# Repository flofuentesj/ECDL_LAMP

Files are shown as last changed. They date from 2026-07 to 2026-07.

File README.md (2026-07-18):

# Optically-feedback-stabilized-ECDL-
A cost-effective diode laser system for high-resolution atomic spectroscopy, developed at Universidad de Concepción's LAMP laboratory using commercial components. It features an external cavity with a piezoelectric transducer for precise wavelength tuning and stabilization that achieves sub-MHz line width essential for rubidium transitions.
Setup: 
Setup

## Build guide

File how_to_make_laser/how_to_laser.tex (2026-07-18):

\documentclass[12pt]{article}
\usepackage[utf8]{inputenc}
\usepackage{geometry}
\usepackage[T1]{fontenc}
\usepackage{amsfonts}
\usepackage{afterpage}
\usepackage{graphicx}
\usepackage{float}
\usepackage{url}
\usepackage{hyperref}
\usepackage{bookmark}
\usepackage[sorting=none]{biblatex}
\usepackage{multirow}
\usepackage[table,xcdraw]{xcolor}
\usepackage{pgf}
\usepackage{xurl}
\usepackage{tabularray}
\usepackage{tabulary}
\usepackage{fancyhdr}
\usepackage[maxfloats=30,morefloats=12]{morefloats}
\usepackage{multicol}
\usepackage[dvipsnames]{xcolor}
\usepackage{awesomebox}
\usepackage{subcaption}
\usepackage{awesomebox}
\usepackage{pgfornament}
\usepackage[export]{adjustbox}
\usepackage{biblatex} %Imports biblatex package
\usepackage{tikzlings}

\addbibresource{howto.bib} %Import the bibliography file
\fontfamily{put}\selectfont
\setlength{\columnsep}{40pt}
\setlength{\voffset}{0.5cm}
\setlength{\headsep}{40pt}
\setlength{\headheight}{34.06914pt} % Fix for fancyhdr error
\addtolength{\topmargin}{-22.06914pt} % Adjusted top margin as suggested by fancyhdr
\geometry{legalpaper, portrait, margin=2.3cm}

% Header and footer
\pagestyle{fancy}
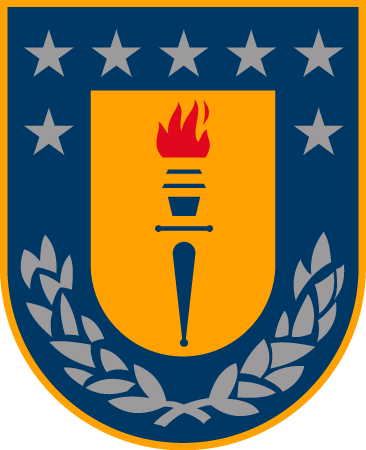
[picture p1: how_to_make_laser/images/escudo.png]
\fancyhead[C]{}
\fancyhead[L]{\textbf{Tópicos II}\\ Universidad de Concepción}
\fancyhead[R]{\textbf{Florencia Fuentes}\\flofuentes2021@udec.cl}
\fancyfoot{}
% for adjust width environment
\usepackage[strict]{changepage}

% for formal definitions
\usepackage{framed}

%\definecolor{formalshade}{rgb}{0.95,0.95,1}
\definecolor{formalshade}{rgb}{.97, .88, .94}

\newenvironment{formal}{
  \def\FrameCommand{
    \hspace{1pt}
    {\color{White}\vrule width 2pt}
    {\color{Lavender}\vrule width 4pt}
    \colorbox{formalshade!40!white}
  }
  \MakeFramed{\advance\hsize-\width\FrameRestore}%
  \noindent\hspace{-4.55pt}% disable indenting first paragraph
  \begin{adjustwidth}{}{7pt}%
  \vspace{2pt}\vspace{2pt}
}
{\vspace{2pt}\end{adjustwidth}\endMakeFramed}

\renewcommand{\headrulewidth}{0.1pt}

\usepackage{tikz}

\usepackage{tcolorbox}
\tcbuselibrary{minted}
\newtcblisting{mybox}{colback=white,minted language=latex,listing side text,righthand width=.5\textwidth}
\usetikzlibrary{ducks}
\usepackage{tikzducks}

\definecolor{titlepagecolor}{cmyk}{0,.49,.15,.11}

\newcommand\titlepagedecoration{%
\begin{tikzpicture}[remember picture,overlay,shorten >= -10pt]

\coordinate (aux1) at ([yshift=-15pt]current page.north east);
\coordinate (aux2) at ([yshift=-410pt]current page.north east);
\coordinate (aux3) at ([xshift=-4.5cm]current page.north east);
\coordinate (aux4) at ([yshift=-150pt]current page.north east);

\begin{scope}[titlepagecolor!70,line width=12pt,rounded corners=12pt]
\draw
  (aux1) -- coordinate (a)
  ++(225:5) --
  ++(-45:5.1) coordinate (b);
\draw[shorten <= -10pt]
  (aux3) --
  (a) --
  (aux1);
\draw[opacity=0.6,titlepagecolor,shorten <= -10pt]
  (b) --
  ++(225:2.2) --
  ++(-45:2.2);
\end{scope}
\draw[titlepagecolor,line width=8pt,rounded corners=8pt,shorten <= -8pt]
  (aux4) --
  ++(225:0.8) --
  ++(-45:0.8);
\begin{scope}[titlepagecolor!70,line width=6pt,rounded corners=8pt]
\draw[shorten <= -10pt]
  (aux4) --
  ++(225:3) coordinate[pos=0.45] (c) --
  ++(-45:3.1);
\draw
  (aux4) --
  (c) --
  ++(135:2.5) --
  ++(45:2.5) --
  ++(-45:2.5) coordinate[pos=0.3] (d);   
\draw 
  (d) -- +(45:1);
\end{scope}
\end{tikzpicture}%
}

\DeclareFixedFont{\titlefont}{T1}{ppl}{b}{it}{0.5in}

\let\hrefWithoutArrow\href

\renewcommand{\href}[2]{\hrefWithoutArrow{#1}{\ifthenelse{\equal{#2}{}}{ }{#2 }\raisebox{.15ex}{\footnotesize \faExternalLink*}}}

\begin{document}
% environment derived from framed.sty: see left bar environment definition
\pagecolor{pink!40!white}\afterpage{\nopagecolor}
%\maketitle

\begin{titlepage}
    \centering

    

    \vspace*{5cm}

    {\Huge\bfseries
    How to Make Your Own Laser at Home\\
    (or in the Lab, Pretty Much the Same Thing)
    \par}

    \vspace{0.2cm}

    {\raggedleft\Large\itshape Tópicos en física II \qquad  \par}

    \vfill

    {\Large \bfseries Florencia Fuentes Jara \par} 

    \vspace{0.1cm}

    \mbox{\hrefWithoutArrow{mailto:flofuentes2021@udec.cl}{\color{magenta}{\footnotesize\faEnvelope[regular]}\hspace*{0.13cm}flofuentes2021@udec.cl}}%

    \vspace{1cm}

    {\large
    Universidad de Concepción\\
    Faculty of Physical and Mathematical Sciences\\
    Department of Physics
    \par}

    \titlepagedecoration
\end{titlepage}

\thispagestyle{fancy}
\newpage
% Table of Contents
\tableofcontents
\thispagestyle{fancy}

\clearpage

% Begin page numbers
\fancyfoot[C]{\thepage}
\pagenumbering{arabic}

% ===============================
% SUMMARY SECTION
% ===============================
\section{Summary}
\addcontentsline{toc}{section}{Summary}
This project presents a comprehensive guide to designing and constructing an in house laser system suitable for atomic physics experiments. This report details the theoretical foundations of laser operation, practical electronics design, hands-on construction techniques, and methods for spectral linewidth narrowing. Our goal is to use them for laser cooling and trapping of alkali atoms, particularly Rubidium 85 and 87. 

% ===============================
% INTRODUCTION SECTION
% ===============================
\section{Introduction}
Lasers have revolutionized modern physics, enabling unprecedented control over atomic and molecular systems. This report documents the development of a custom laser system design for atomic physics experiments, specifically targeting applications in laser cooling and magneto-optical trapping (MOT). The motivation arises from the need for affordable, customizable laser sources in research and education settings. We present a step-by-step approach to laser construction, from basic electronic components to advanced optical feedback techniques.

% ===============================
% THEORY SECTION
% ===============================
\section{Theory: The Physics Behind}
\subsection{What is a Laser?}
A laser (Light Amplification by Stimulated Emission of Radiation) is a device that generates coherent, monochromatic, and highly directional light through the process of stimulated emission. Unlike conventional light sources that emit radiation through spontaneous emission (resulting in incoherent, polychromatic light), lasers produce light waves that are in phase both temporally and spatially.

\begin{center}
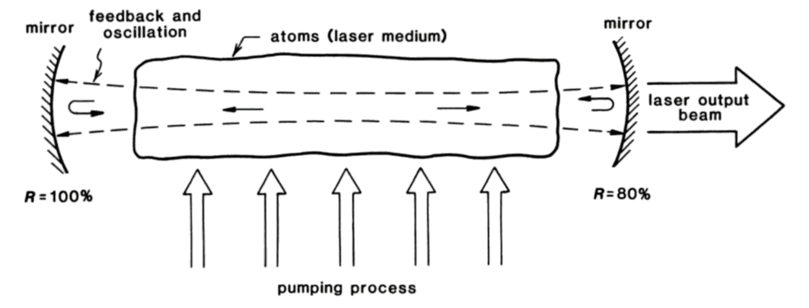
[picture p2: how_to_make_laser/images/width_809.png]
 
\end{center}

\begin{itemize}

    \item \textbf{Stimulated Emission:} When an atom or molecule in an excited state encounters a photon with energy equal to the transition energy to a lower state, it can be stimulated to emit a second photon identical in frequency, phase, polarization, and direction to the incident photon.

    \item \textbf{Population Inversion:} For stimulated emission to dominate over absorption, more atoms must occupy the excited state than the ground state a condition known as population inversion. This non-thermal equilibrium state is achieved through pumping, where external energy (electrical, optical, or other forms) excites the gain medium.

    \item \textbf{Optical Feedback:} An optical resonator (typically formed by two mirrors) provides positive feedback, allowing photons to make multiple passes through the gain medium, stimulating further emission. One mirror is partially transmissive, allowing a fraction of the amplified light to escape as the laser beam.

\end{itemize}

Some essential characteristics of lasers are: coherence, monochromaticity, directivity, and brightness.

\subsection{Why Do We Need Them For?}
In our case we will use Laser diodes due to their compactness, efficiency, direct electrical pumping, compatibility with specific atomic transitions such as Rubidium D-lines at 780 nm and 795 nm, tunability, and cost-effectiveness for laboratory use.
\\
The external cavity configuration we employ enhances the basic laser diode's performance by narrowing its linewidth and in near future enabling mode-hop-free tuning, making it suitable for precision spectroscopy and laser cooling experiments.

\section{Atomic Physics Experiments}
Lasers have changed experimental atomic physics by allowing precise spectroscopy and control of atomic systems. They are essential for exploring quantum phenomena, testing nature's symmetries, and advancing quantum technologies. This section discusses lasers' roles in measuring and manipulating atomic systems, focusing on alkali atoms and cold atoms.

\subsection{Alkali Atoms: Rubidium 85 and 87}
Rubidium is a soft, ductile alkali metal, composed naturally of two stable isotopes, 85Rb and 87Rb, in the following ratio; $72.15$ \% corresponds to 85Rb and $27.85$ \% to 87Rb. The D2 line of Rubidium 85 and 87 has a natural linewidth (FWHM) of $6.07$ MHz~\cite{steck85,steck87}, which is the transition we will use for cooling and trapping atoms in a Magneto\- Optical Trap (MOT). 

\begin{figure}[H]
    \begin{subfigure}{0.45\textwidth}
        \centering
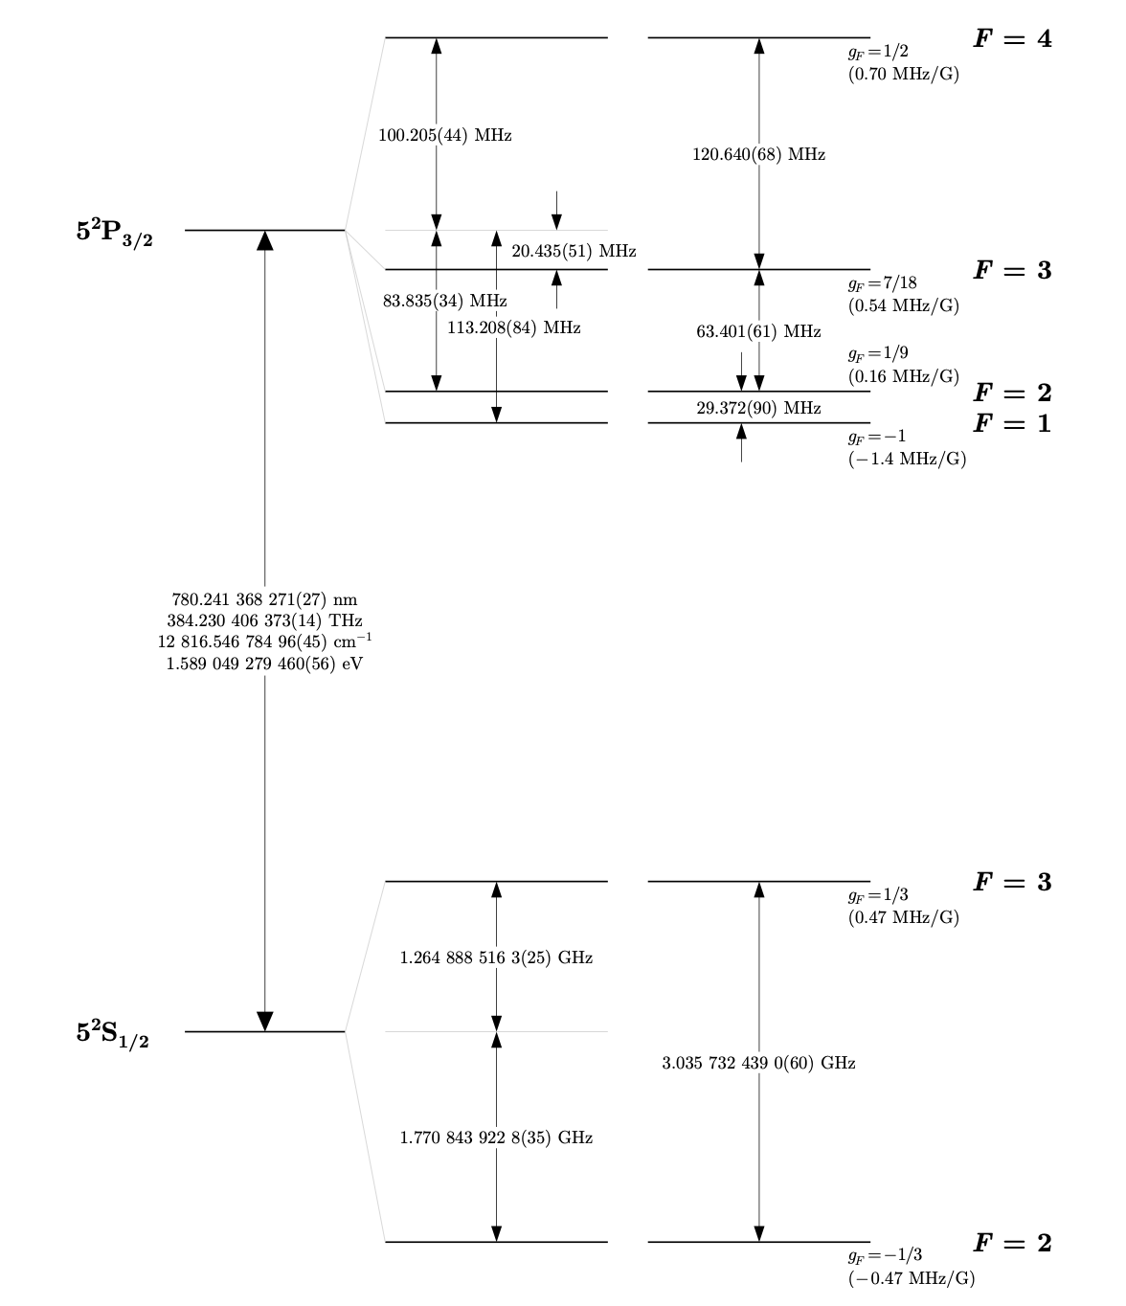
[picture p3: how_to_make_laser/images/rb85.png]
        
    \end{subfigure}
    \hfill
    \begin{subfigure}{0.45\textwidth}
        \centering
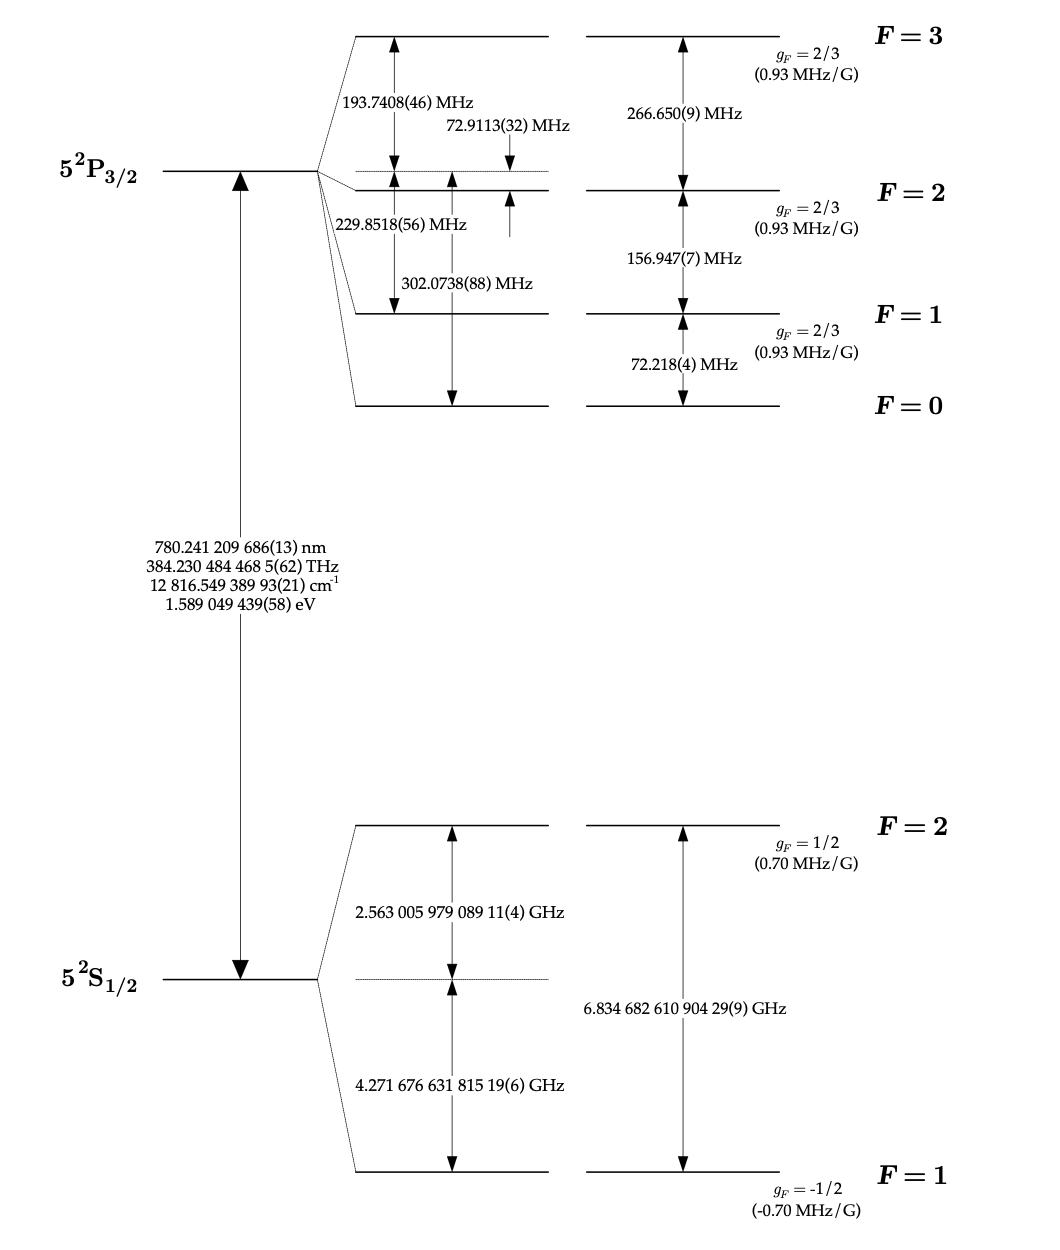
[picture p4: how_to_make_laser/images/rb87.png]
        
    \end{subfigure}
 \caption{Rubidium 85 and 87 D2 transition hyperfine structure, with frequency splittings between the hyperfine energy levels.}
\end{figure}

\subsection{Laser Cooling and Trapping of Atoms}

Laser cooling uses light-matter momentum transfer to slow atomic motion, achieving temperatures as low as microkelvin. In Doppler cooling, the foundational technique, counter-propagating laser beams tuned slightly below an atomic resonance (e.g., Rb-87’s D$_2$~line at 780~nm) create a velocity-dependent damping force that reduces kinetic energy~\cite{foot}. This cooling enables optical molasses, where atoms scatter photons cyclically, reaching temperatures near the Doppler limit $T_D=\frac{\hbar \Gamma}{2 k_B}$~\cite{molasses}.
\medskip

\subsection{Magneto-Optical Trap (MOT)}
For trapping, magneto-optical traps (MOTs) combine laser cooling with quadrupole magnetic fields to confine atoms at densities up to $10^8 $atoms/cm$^3$~\cite{Phillips}. The MOT uses six laser beams arranged symmetrically around the trap center, tuned to the red of the atomic resonance, and a magnetic field gradient to create a restoring force that arises from Zeeman shift enhanced scattering in regions of non-zero field gradient, creating a net restoring force toward the trap center. Radiation pressure from the lasers balances this force, enabling stable, long-term confinement of ultracold atomic ensembles~\cite{Rabb}.

\begin{figure}[ht]
    \centering
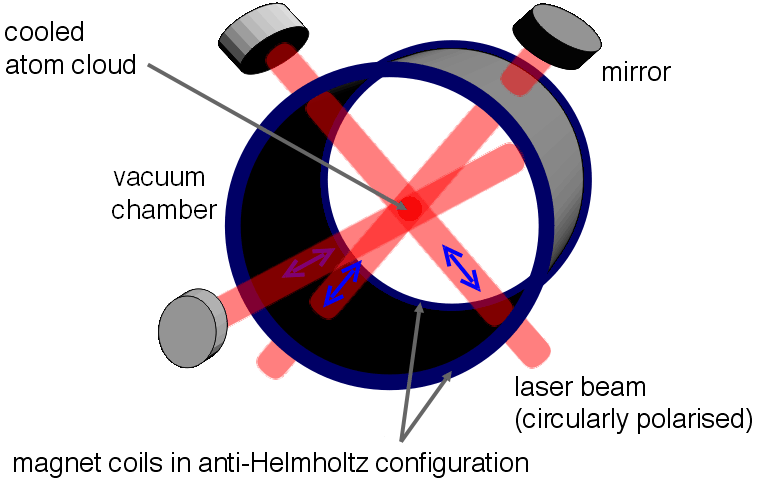
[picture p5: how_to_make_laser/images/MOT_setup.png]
    
    \caption{Magneto-Optical Trap (MOT) setup~\cite{MOTsetup}.}\label{fig:MOT_setup}
\end{figure}
Critical to both Doppler cooling and MOT confinement is precise laser linewidth stability ($\Delta \nu < \Gamma \approx 6$ MHz for Rb-87) and intensity control. Narrow linewidth ensures resonant photon scattering for efficient momentum transfer, while stabilized intensity maximizes scattering rates without causing excessive heating or loss of atoms. Achieving these requirements necessitates advanced laser systems, often involving external cavity configurations and optical feedback techniques.
\section{How do we measure the linewidht of the laser: Self-Heterodyne Spectroscopy}
To measure the linewidth of our laser system, we employ self-heterodyne spectroscopy, a technique based on the Wiener-Khintchine theorem. This method involves splitting the laser beam into two paths—one delayed by a time $\tau$ relative to the other—and then recombining them on a photodetector. The interference pattern yields the power spectral density (PSD), which reveals the laser's coherence properties.

\begin{formal}
\textbf{Power Spectral Density Function:}
The PSD derived from the Wiener-Khintchine theorem for our setup is:
\begin{equation}
    S(\omega, \tau) = \frac{\frac{1}{2} P_0^2 \tau_c}{1 + {\omega \pm \Omega}^2 \tau_c^2} \left\{ 1 - e^{-\frac{-|\tau|}{\tau_c}} [\cos(\omega \pm \Omega)] \tau \right\} + \frac{\sin(\omega \pm \Omega) |\tau|}{(\omega \pm \Omega) \tau_c} + \frac{1}{2} P_0^2 \pi e^{-\frac{-|\tau|}{\tau_c}} \delta(\omega \pm \Omega)
\end{equation}
where $\tau_c$ is the coherence time, $\Omega$ is the frequency shift from an acousto-optic modulator (AOM), and $P_0$ is the laser power. This model predicts two regimes: when $\tau \gg \tau_c$, the spectrum collapses to a pure Lorentzian; when $\tau \ll \tau_c$, it shows a narrow delta function peak. Achieving sub-MHz linewidths typically requires fiber delays of tens of kilometers, which is impractical for most laboratories. Our approach uses optical feedback to achieve narrow linewidths without such long delays~\cite{Richter1986}.
\end{formal}

\begin{figure}[H]
    \centering
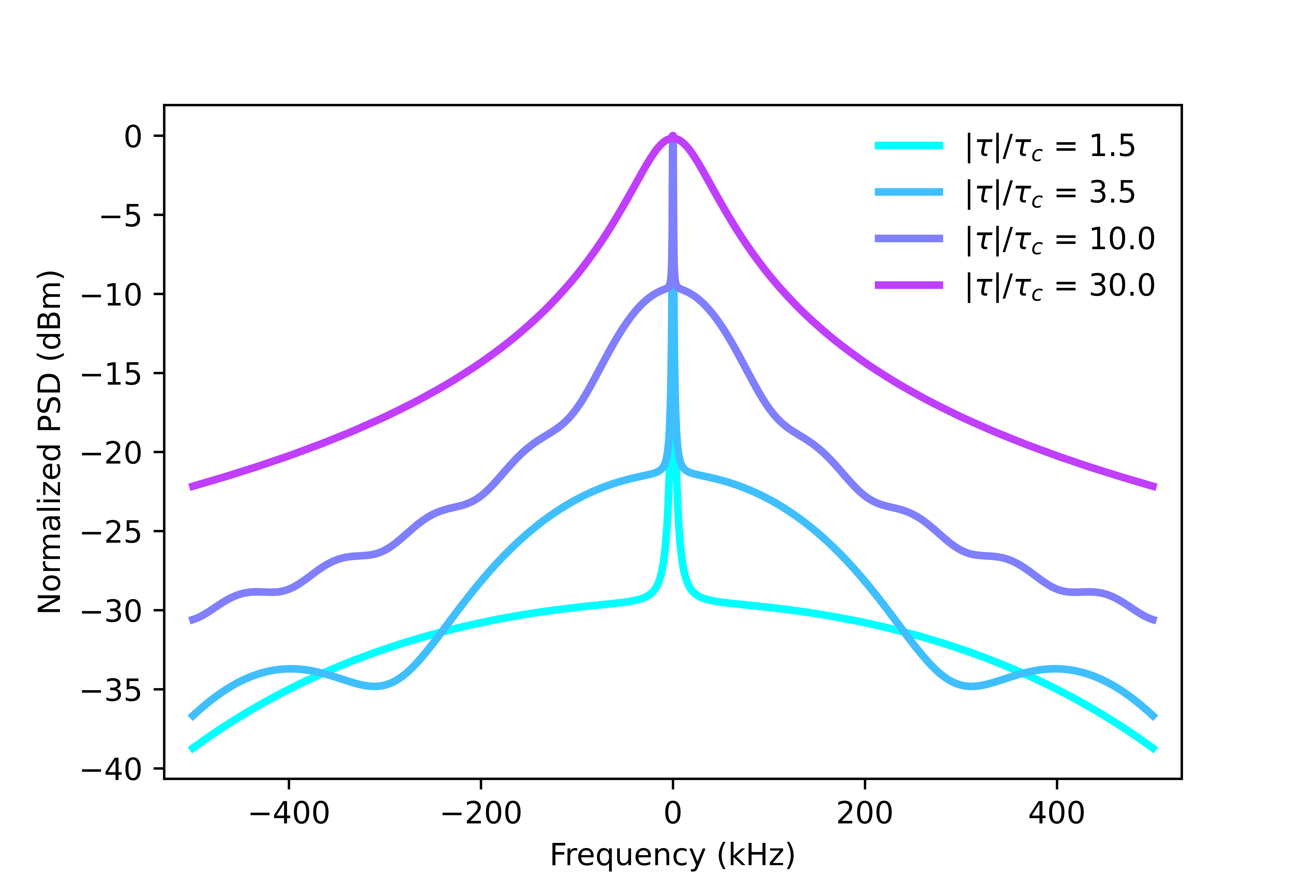
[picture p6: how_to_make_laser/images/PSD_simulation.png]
    
    \caption{Simulation of the power spectral density model in different regimes of coherence. The transition from coherent to incoherent interference is evident as the delay time increases relative to the coherence time.}\label{fig:psd_simulation}
\end{figure}

\section{How Can We Build Our Own Laser?}
The steps involved in creating a functional laser system are described in this section. It covers choosing components, circuit design, optical alignment, and optimization methods. The method seeks to address particular requirements for atomic physics experiments and emphasizes the integration of theory and practice.

\subsection{Electronics}
Electronic control systems are vital for stable laser systems, focusing on current regulation, temperature stabilization, and frequency locking. Key circuits include the current driver, temperature stabilization, and lock-in amplifier for reliable atomic physics experiments.\cite{scherz2016practical}

 \subsubsection{Basic Components: Resistance, Capacitance, Inductance}
Electronic circuits for laser control utilize three fundamental passive components:
\begin{itemize}
    \item \textbf{Resistors:} The characteristic by which it oppose the flow of current is known as resistance. The resistance of a resistor is denoted by symbol R and measured in Ohms ($\Omega$). The typical circuit symbol of a resistor is shown in the following figure.
    \begin{figure}[ht]
        \centering
        
    \end{figure}\\
    Resistors are used to set operating current and signal levels in circuits, provide voltage reduction, set precise gain values in precision circuits, act as shunts in ammeters and voltage meters, behave like damping agents in oscillators and timer circuits, act as bus and line terminators in digital circuits, provide feedback networks for amplifiers, and act as pull up and pull down elements in digital circuits.
        \begin{formal}
        \textbf{OHM's Law:}
        \\  The linear relationship between voltage ($V$), current ($I$), and resistance ($R$):
            \begin{equation}
                V = IR \nonumber
            \end{equation}
         This equation rule the current flow through resistive elements, allowing us to calculate voltage drops, power dissipation ($P = I^2R = V^2/R$). 
         
         %For AC circuits with reactive components (capacitors and inductors), this relationship extends to complex impedance ($Z$), where $V = IZ$, with impedance depending on frequency due to the phase shifts introduced by capacitance and inductance.

        \end{formal}

    \item \textbf{Capacitors:} Their major function is simple energy storage, where charge from an applied current is stored within the capacitor and later released back into the circuit as useful current. The rate of charging and discharging can be controlled by placing a resistor in series with the capacitor. This effect is often used in high-current discharge circuits, as well as small energy backup supplies for low-power memory Integrated circuits(ICs). It is also used to smooth out power supply ripple, control timing in ICs, and alter the shape of waveforms.
    
    \begin{figure}[h!]
        \centering
        
    \end{figure}

    \item \textbf{Inductors:} The inductor is basically a wire of finite length twisted into a coil and has a property, known as inductance, which oppose any change in the electric current.
   
    \begin{figure}[h!]
        \centering
        
    \end{figure}

    \begin{formal}
        \textbf{Inductance:}
        The voltage across an inductor is proportional to the rate at which the current changes. The relationship between voltage and current are described by the following equations:
        \begin{equation}
            V_L = L \frac{dI_L}{dt} 
        \end{equation}
        
        \begin{equation}
            I_L= \frac{1}{L}\int V_L
        \end{equation}

    \end{formal}
\end{itemize}

\subsubsection{Active components}
 Active components control current flow and amplify signals using external power sources, enabling precise laser regulation.

\begin{itemize}
    \item \textbf{Semiconductors:}
    A semiconductor is a material whose electrical conductivity lies between a conductor and an insulator. This unique property makes semiconductors ideal for controlling electrical current, enabling their use in a wide range of electronic devices. 
    \begin{itemize}
        \item \textbf{Diodes:} A two-lead semiconductor device that acts as a one-way gate to electric current flow. When a diode’s anode lead is made more positive in voltage than its cathode lead the condition is referred to as forward biasing so the current is permitted to flow through the device.
        
        \begin{figure}[h!]
            \centering
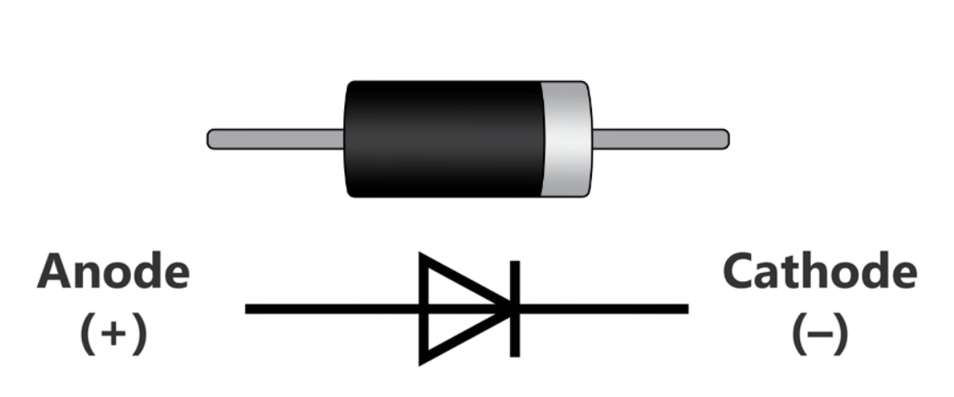
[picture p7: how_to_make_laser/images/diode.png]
            
        \end{figure}
        
        \item \textbf{Transistors:} Three-terminal semiconductor devices that amplify or switch electronic signals. Bipolar Junction Transistors (BJTs) are current-controlled and excel in linear, low-noise applications like current regulators, while Metal-Oxide-Semiconductor Field-Effect Transistors (MOSFETs) are voltage-controlled and offer fast switching with minimal gate current, ideal for pulse-width modulation (PWM) in temperature controllers.
        
        \begin{figure}[ht!]
                \centering
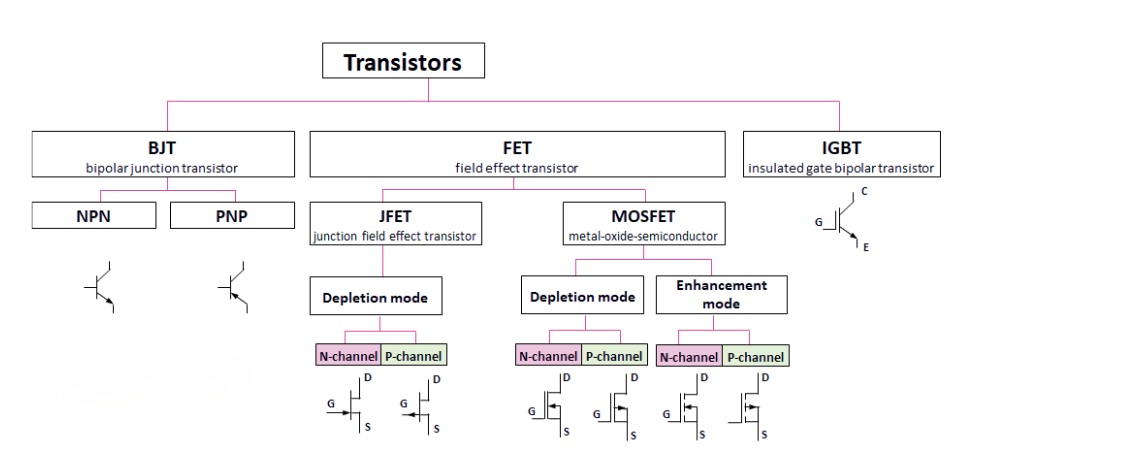
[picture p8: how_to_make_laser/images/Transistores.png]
                
        \end{figure}
            
    \end{itemize}
    \item \textbf{Amplifiers:} They are essential circuits for increasing signal amplitude while preserving signal integrity, playing critical roles in laser control systems for error signal processing, photodetector signal conditioning, and driving control elements.
    
    \begin{itemize}
        \item \textbf{Operational Amplifiers:} Op amps are high gain differential amplifiers with two inputs (inverting and non-inverting) and a single output. In ideal behavior, they have infinite open loop gain, infinite input impedance, zero output impedance, and infinite bandwidth. Real op amps approach these ideals with specifications tailored to specific applications.
        
        \begin{figure}[H]
                \centering
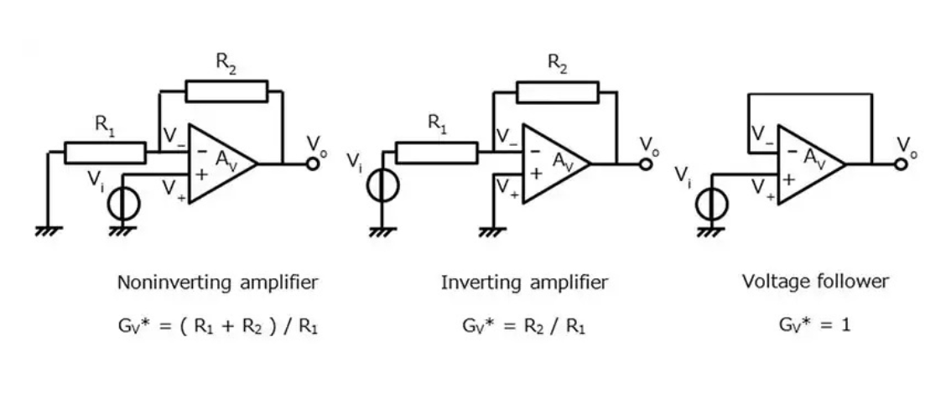
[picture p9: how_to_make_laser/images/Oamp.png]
                
        \end{figure}

        \begin{formal}
            \textbf{Gain:} The amplification factor of a circuit, defined as the ratio of output to input signal. For voltage amplifiers, $A_v = V_{out}/V_{in}$; in decibels, $G_{dB} = 20\log_{10}(A_v)$. Determines sensitivity of feedback loops and must be optimized for stability versus response speed.
        \end{formal}

        \item \textbf{Instrumental Amplifiers:} INAmp is a high precision differential amplifier designed to amplify small signals from sensors while rejecting common mode noise, featuring high input impedance, high gain, and excellent common mode rejection ratio (CMRR).
        
    \end{itemize}

\end{itemize}

\subsubsection{Low and high pass filters:}
Low-pass and high-pass filters are essential for controlling a signal's frequency content. A low-pass filter allows low-frequency signals to pass through while reducing the amplitude of higher-frequency signals, and a high-pass filter does the opposite, allowing high frequencies to pass through while blocking low-frequency components. 

\begin{figure}[ht!]
        \centering
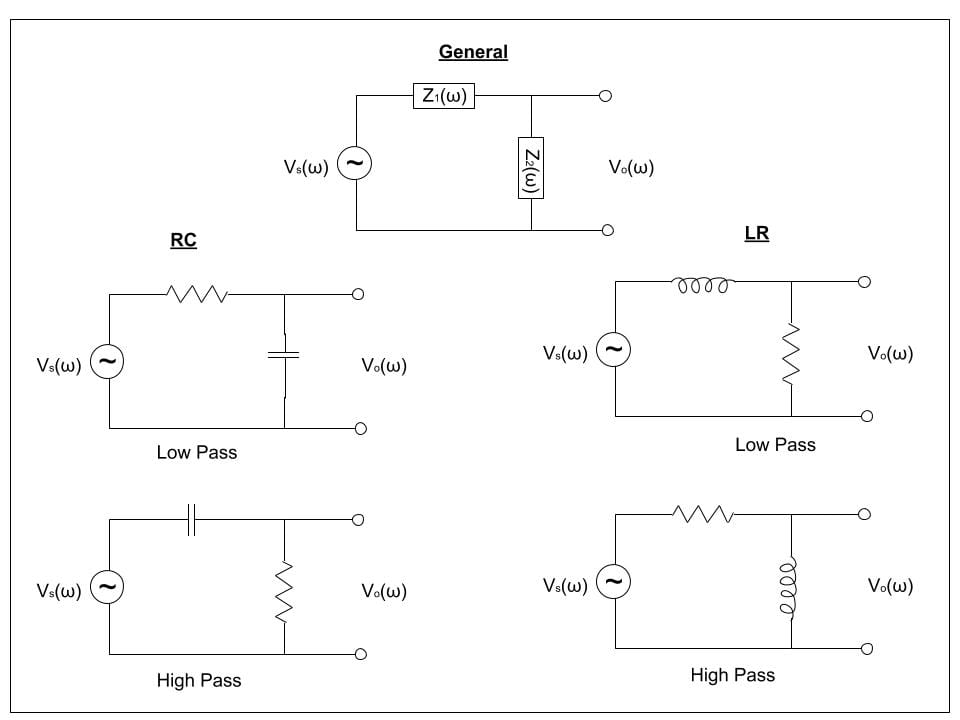
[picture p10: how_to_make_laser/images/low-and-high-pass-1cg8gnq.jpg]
        
        \caption{ The low and high-pass versions of the RL and RC circuits. $V_s(w)$ is the voltage of the function generator and $V_o(w)$ is the voltage on the oscilloscope.}
    \end{figure}

\begin{formal}
    \textbf{Impedance ($Z$):} generalizes resistance to AC circuits, representing the total opposition a circuit presents to alternating current flow. While resistance dissipates energy as heat, impedance includes both resistive and reactive components which store and release energy without dissipation. In complex notation, $Z = R + jX$, where $X$ is the reactance that depends on frequency: capacitive reactance $X_C = -1/(\omega C)$ decreases with frequency, while inductive reactance $X_L = \omega L$ increases.
\end{formal}

\subsection{Optoelectronics: Laser Diodes}

Laser diodes are light emitting diodes with two “mirrors” on the surface of the diode to create a laser cavity. When the diode is forward biased, charges are injected into the active area of the junction, while electrons and holes recombine in the junction, creating spontaneous emission of photons. These photons can cause other electron hole pairs to recombine by stimulated emission. When the current is high enough, the device lases.\cite{Paschotta_2005_laser_diodes} 

\begin{figure}[ht!]
        \centering
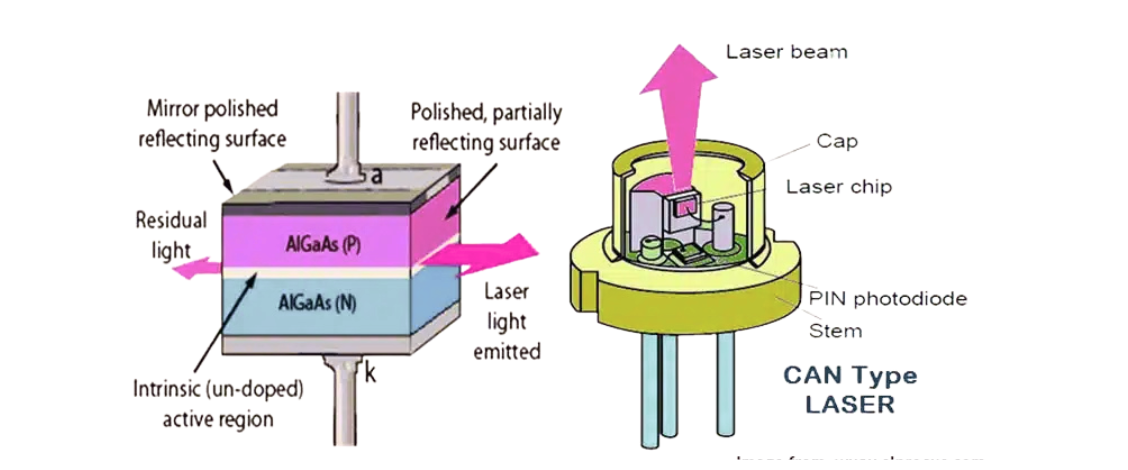
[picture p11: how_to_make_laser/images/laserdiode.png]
        
    \end{figure}

\subsection{Hands-On Construction}

The electronic control system is constructed from four independent but interconnected circuits, each addressing a specific aspect of laser stabilization. All circuits are built on custom designed printed circuit boards (PCBs) to minimize noise, improve reliability, and facilitate troubleshooting.

\subsubsection{Negative Current Control Circuit:}
The laser diode driver requires precise, low noise current regulation. We implement a negative feedback current controller\footnote{For more details of the ncc circuit see APPENDIX ~\ref{apx}} that maintains constant current despite fluctuations in diode voltage and temperature.

\begin{figure}[h!]
        \centering
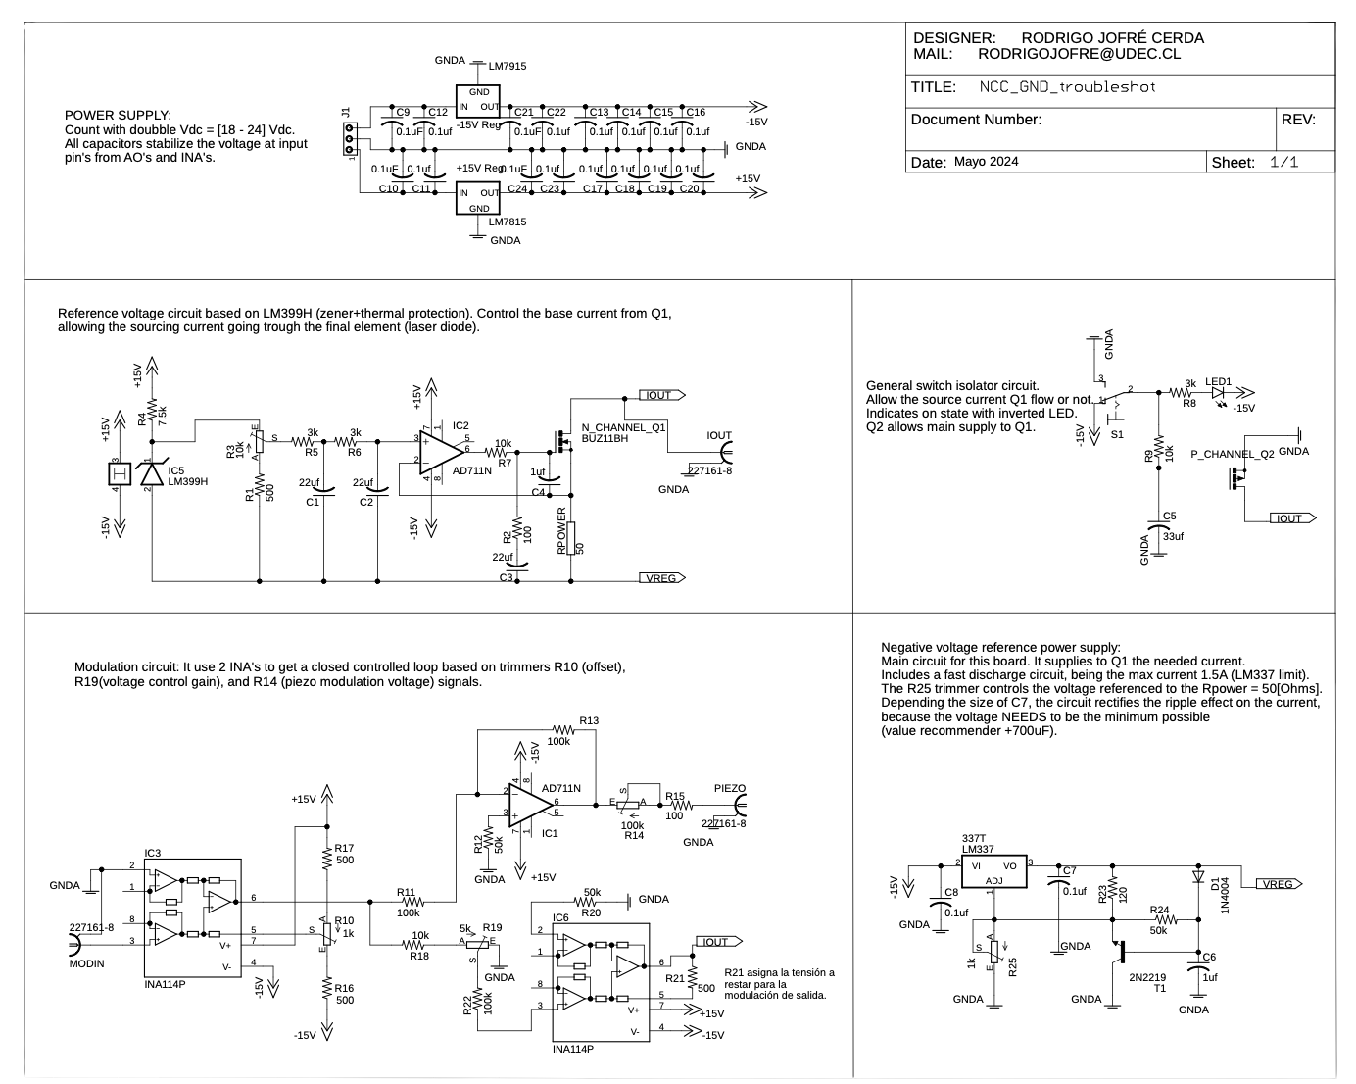
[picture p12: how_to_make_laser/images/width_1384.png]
        
\end{figure}

\subsubsection{Thermoelectric Circuit:}
Temperature stabilization is critical for wavelength control, as diode wavelength shifts approximately 0.3 nm/\(^\circ C\). We designed a thermoelectric cooler (TEC) controller using a dual operational amplifier
configuration. The first stage amplifies the voltage difference between a thermistor and a reference voltage, producing an error signal. The second stage, with adjustable gain, drives the TEC to maintain the laser diode at a constant temperature. The circuit includes protection diodes to prevent reverse current and large capacitors to stabilize the control voltage.

\begin{figure}[H]
    \centering
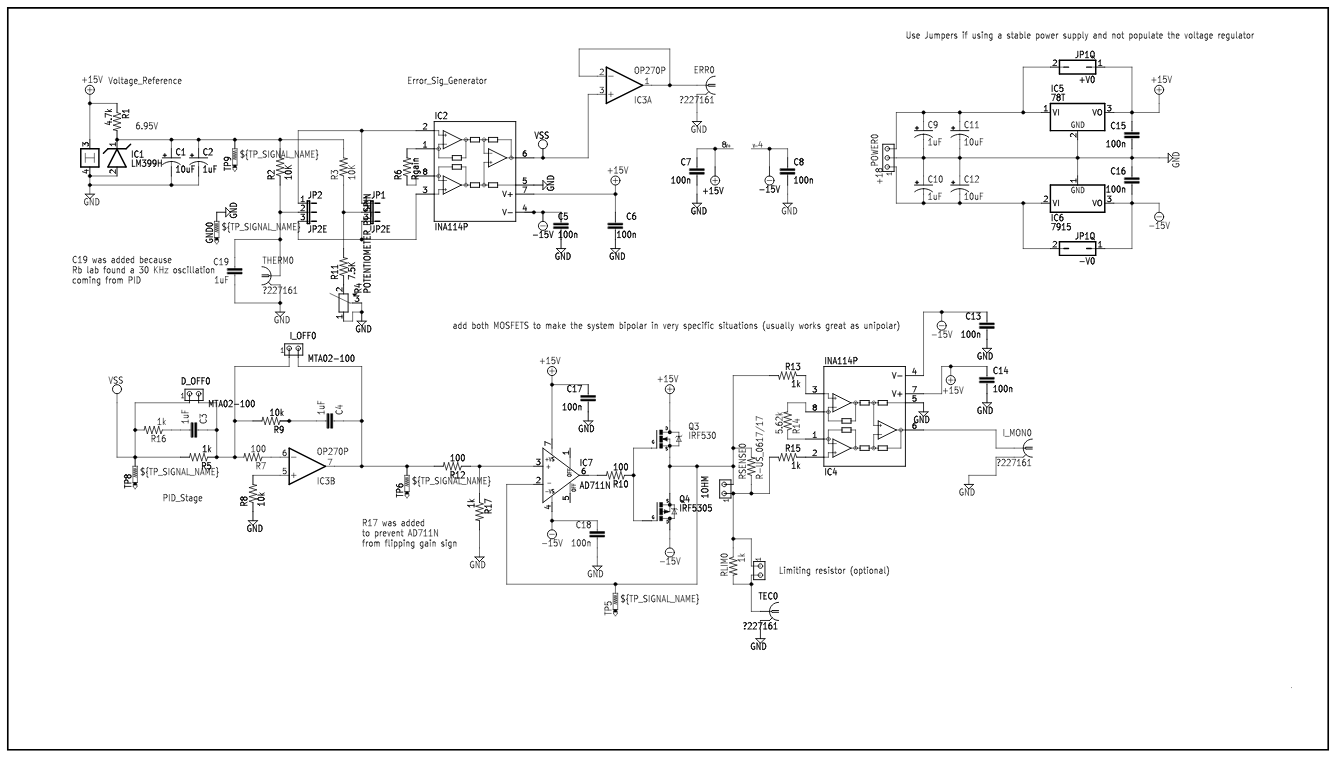
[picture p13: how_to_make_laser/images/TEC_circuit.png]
    
    \caption{Thermoelectric control circuit.}\label{fig:tec_circuit}
\end{figure}

\subsubsection{PID controller circuit:}
The PID circuit is often utilized as a control loop feedback controller. The letters making up the acronym PID correspond to Proportional (P), Integral (I), and Derivative (D), which represents the three control settings of a PID circuit. The PID circuit actively controls the system so as to hold it at the set point by generating an error signal that is essentially the difference between the set point and the current value. The three controls relate to the time-dependent error signal.
%https://www.thorlabs.com/driver-pid-settings?tabName=PID%2520Tutorial

\begin{figure}[H]
    \centering
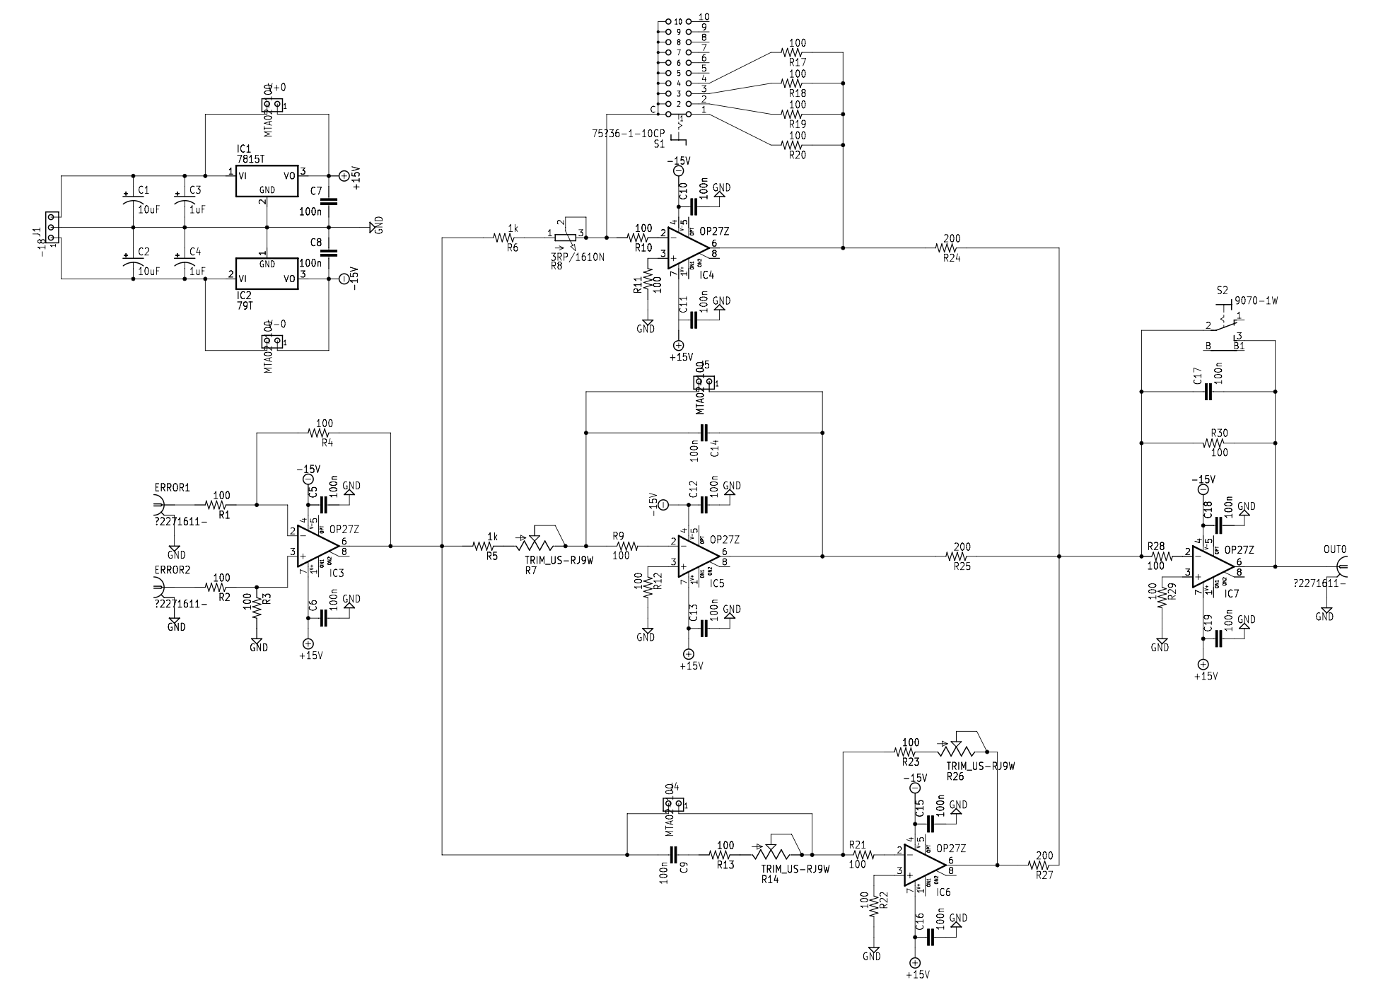
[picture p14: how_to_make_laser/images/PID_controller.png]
    
    \caption{PID controller circuit.}\label{fig:pid_circuit}
\end{figure}

\subsubsection{Lock-in Circuit:}
This circuit extracts the error signal from reflected laser light by mixing it with a reference
modulation frequency.

\begin{figure}[H] 
    \centering 
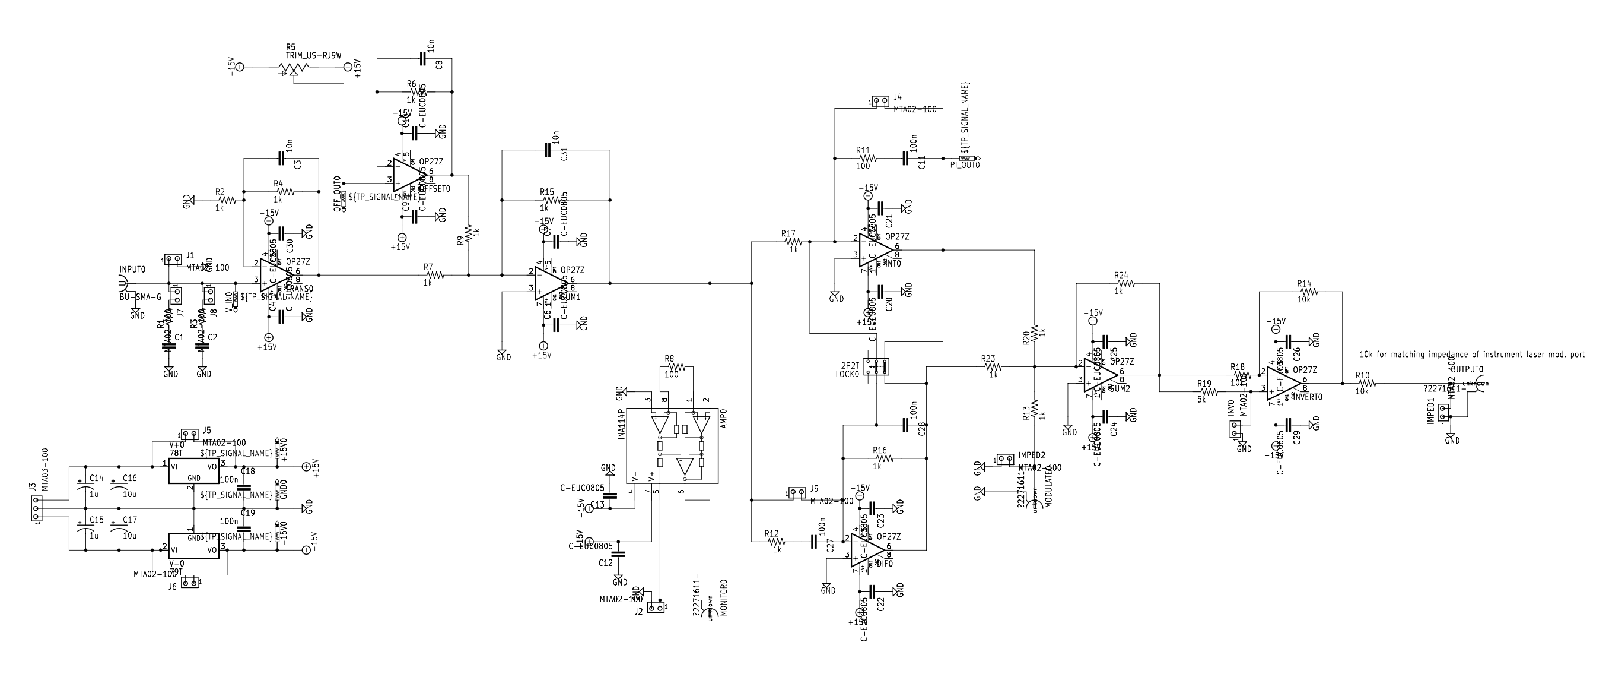
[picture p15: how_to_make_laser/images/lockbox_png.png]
    
    \caption{Lock-in amplifier circuit}\label{fig:lockin_circuit} 
\end{figure}

\subsubsection{PCB Design and Soldering:}
    All circuits were fabricated on custom-designed printed circuit boards (PCBs) to minimize noise and ensure reliability. Soldering was performed using a temperature-controlled soldering iron  with proper flux application. Sensitive components like the laser diode were soldered quickly to prevent thermal damage. 

\section{Optics:}
\subsection{Optical elements}
    Our laser system employs several key optical components:
    \begin{itemize}
        \item \textbf{Diffraction grating:} is an optical device exploiting the phenomenon of diffraction. It contains a periodic structure, which causes spatially varying optical amplitude and/or phase changes.\cite{Paschotta_2013_diffraction_gratings}
        \item \textbf{Beam splitter:} They separate incident light into two or more beams of the same wavelength. 
        \item \textbf{Acusto-Optic Modulator(AOM):} is a device which can be used for controlling the transmitted power of a laser beam with an electrical drive signal.\cite{Paschotta_2019_acousto_optic_modulators}
        \item \textbf{Piezoelectric transducer (PZT):} For fine adjustment of grating angle, the crystals produce a pressure when deformed by an applied voltage and produce a voltage when deformed by an applied pressure
        \item \textbf{Photodetectors:} Sensors that convert incident light into measurable electrical signals.
    \end{itemize}

\subsection{Narrowing the Linewidth}
% chktex 39

\subsubsection{External Cavity in a Laser Diode:} 
    We extended the laser cavity externally by adding a diffraction grating, which provides wavelength selective feedback. The external cavity length  increases the photon lifetime in the cavity, effectively narrowing the linewidth. 

\subsubsection{Optical Feedback:} 
    Controlled optical feedback from the diffraction grating narrows the linewidth through regenerative amplification. We optimized the feedback ratio to approximately $10-30$ \% of the output power. Too little feedback provides insufficient narrowing, while too much can cause instability or mode hops.

\subsection{Experimental Setup}
    \begin{figure}[H]
        \centering
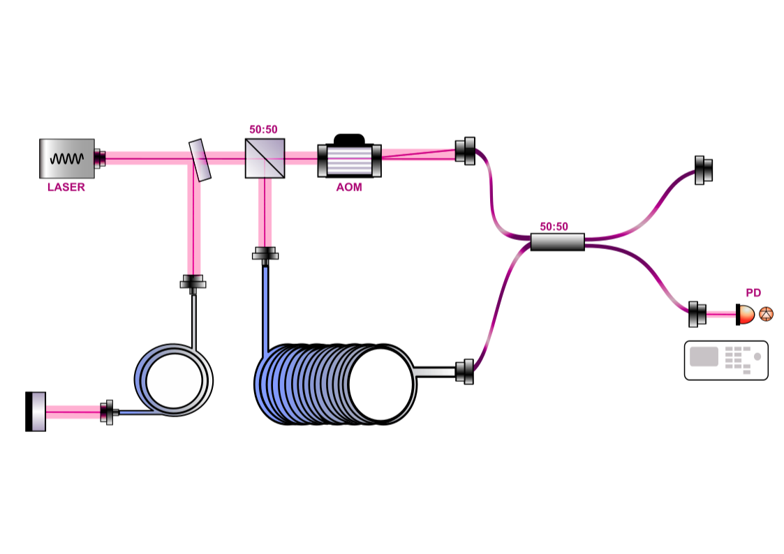
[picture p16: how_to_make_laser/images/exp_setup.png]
        
        \caption{Schematic representation of the experimental setup for feedback stabilized diode laser.}\label{fig:experimental_setup}
    \end{figure}

% \subsubsection{Littrow Configuration:} 
%     T1he Littrow is where the first\- order diffraction returns directly to the diode, maximizing efficiency. The grating equation for this configuration is:

%         \begin{equation}
%             \lambda = \frac{2d}{m} \sin\theta
%         \end{equation}

% where $d$ is the grating period (556 nm for 1800 lines/mm), $m$ is the diffraction order (1), and $\theta$ is the incidence angle ($\approx$ 45° for 780 nm).

%\subsubsection{Mode-Hop-Free Tuning:} 

% ===============================
% RESULTS SECTION
% ===============================
\section{Results}

We successfully constructed and characterized our in-house laser system, focusing on linewidth reduction through optical feedback stabilization. The performance was quantified using self-heterodyne spectroscopy with a fiber delay, allowing precise measurement of the laser's power spectral density (PSD) and coherence time.

\begin{figure}[H]
    \begin{subfigure}{0.45\textwidth}
        \centering
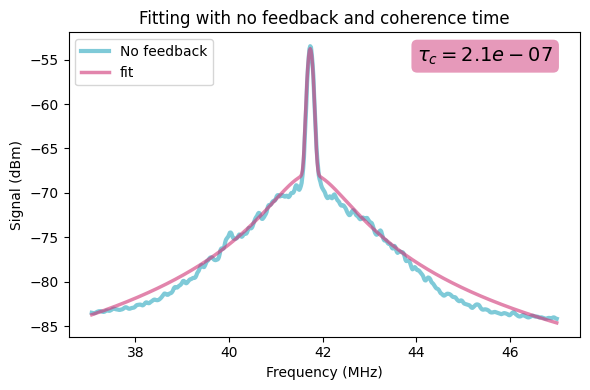
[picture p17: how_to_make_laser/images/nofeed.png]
        
        \caption{Without feedback}
    \end{subfigure}
    \hfill
    \begin{subfigure}{0.45\textwidth}
        \centering
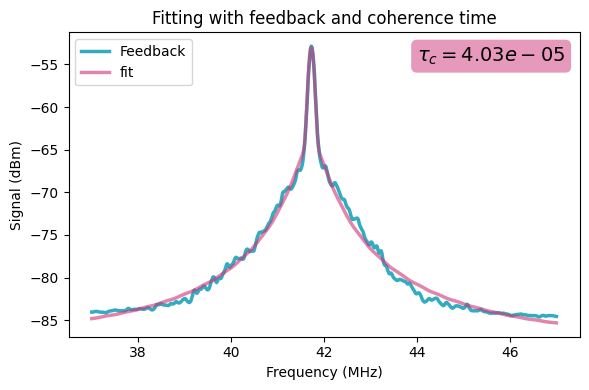
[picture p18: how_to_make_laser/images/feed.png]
        
        \caption{Width feedback}
    \end{subfigure}
 \caption{Measured power spectral density (PSD).}
\end{figure}

The coherence time $\tau_c$ increased from $2.1\times 10^{-7}$ s (without feedback) to $4.03\times 10^{-5}$ s (with feedback), corresponding to coherence lengths of 63 m and 12.1 km, respectively. This dramatic improvement enables precise spectroscopy of rubidium's hyperfine transitions.

% ===============================
% CONCLUSION SECTION
% ===============================
\section{Conclusion}

We have successfully designed, constructed, and characterized an in-house, low-cost, optically feedback stabilized diode laser system suitable for atomic physics experiments. Our work demonstrates that resource constrained laboratories can develop high performance laser systems through careful design and integration of commercial components. Future work will focus on integrating the laser into a complete magneto-optical trap system.

\vfill
\begin{flushright}
    \begin{tikzpicture}
        \duck[body=pink, unicorn=magenta!60!violet, longhair=magenta!60!violet, signpost=\parbox{2cm}{\tiny\color{black}\centering Bye! }, signcolour=brown!70!gray, signback=white!80!purple, shift={(2.5,0)}]      
\end{tikzpicture}
\end{flushright}

\newpage
% ===============================
% REFERENCES SECTION
% ===============================
\section*{References}
\addcontentsline{toc}{section}{References}
% Add your bibliography entries here
%\nocite{*}
\printbibliography[heading=none]
\newpage
% ===============================

%\noindent\makebox[\linewidth]{\rule{\paperwidth}{0.4pt}}
%\notebox{aaaaa}
%\awesomebox{5pt}{\faCertificate}{magenta}{aaa}
%\pgfornament[color=Mahogany,width=2cm]{8}
%
% APPENDIX (Optional)
% ===============================
\appendix~\label{apx}
\addcontentsline{toc}{section}{APPENDIX}
\paragraph{\Huge APPENDIX}
\section{Circuit Diagrams NCC:}
\subsection{Controlled dual power source (PS):}\label{ps}
 This setup uses two reference voltages to send the right amount of current to the Peltier system, which helps control the temperature.The circuit can provide strong output power. Each IC5 and IC6, which are integrated circuits, can handle up to 1.5A of current, or 3A total for the whole circuit, when the voltage is 18 volts direct current.Capacitors are included to keep the voltage signals steady for the main ICs in the industrial control system.

    \begin{figure}[ht!]
            \centering
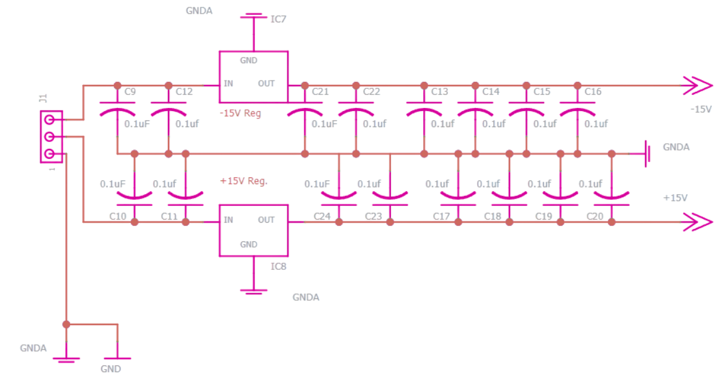
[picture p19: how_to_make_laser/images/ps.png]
            
    \end{figure}

\subsection{Controlled negative power source (NCC):}\label{ncc}

The negative voltage control is the most important aspect of our circuit. Because the laser needs a precise negative voltage to function correctly, this setup is essential. The LM337 regulator enables us to continuously vary the voltage between -1.2 V and -37 V. To prevent fluctuations, we also employ an NPN transistor with a rectifier diode, as well as a potentiometer for precise tuning. Input and output capacitors are also included to reduce noise and stabilize the current. This system maintains a steady voltage for the laser, avoiding instabilities that might impair the quality of the produced beam."

\begin{figure}[ht!]
            \centering
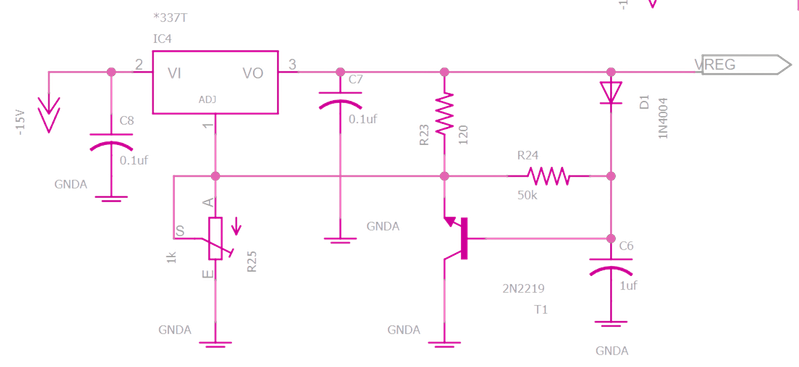
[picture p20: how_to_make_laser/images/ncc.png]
            
    \end{figure}

\subsection{Current control circuit (CC):}\label{cc}

Current management is another essential component of laser operation. We employ an LM399H-based circuit for this purpose, a high-stability, low-noise Zener diode utilized for accurate voltage references. Plus, we use an AD711N operational amplifier to compare the input voltage to a set reference, which helps to keep the laser's power supply current within ideal limits. The voltage-to-current conversion is regulated by a MOSFET, which serves as the control element, in order to avoid overloads and variations. This circuit helps us minimize signal noise, which is critical for achieving a high-quality, stable laser for spectroscopy.

    \begin{figure}[H]
            \centering
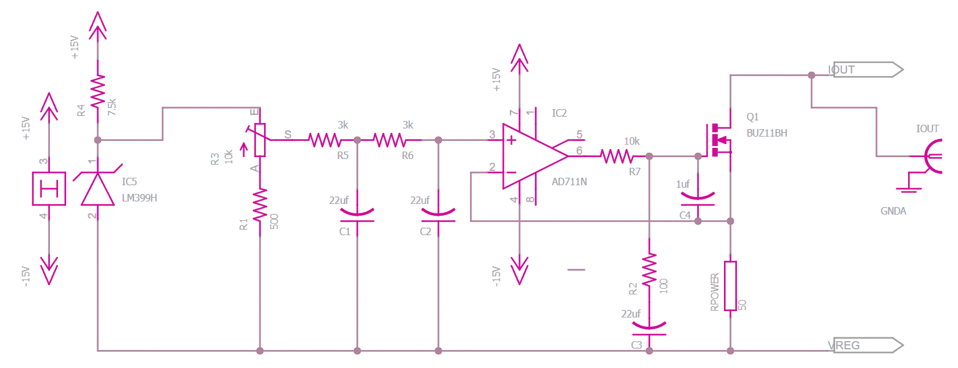
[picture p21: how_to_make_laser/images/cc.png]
            
    \end{figure}

\subsection{General control circuit (Switch):}\label{switch}

This circuit enables to on/off the laser and is the last checkup before damaging the laser diode.

    \begin{figure}[H]
            \centering
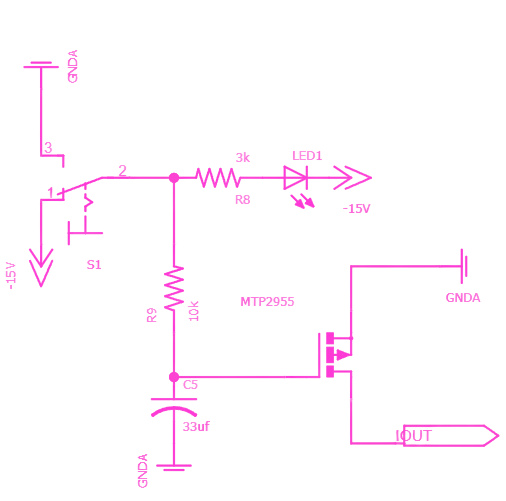
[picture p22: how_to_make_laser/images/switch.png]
            
    \end{figure}

\subsection{Modulation circuit (Mod):}\label{mod}
We implemented a modulation system that enables us to control the output power while simultaneously maintaining the beam frequency in order to enhance laser performance. Voltage modulation of the laser enables precise control over its intensity. Additionally, the laser's optical cavity is dynamically controlled by a piezoelectric element-based stabilization system. This system is especially helpful in spectroscopic applications, where it is essential to maintain beam coherence and avoid jumps that could compromise the precision of the measurement."

    \begin{figure}[H]
            \centering
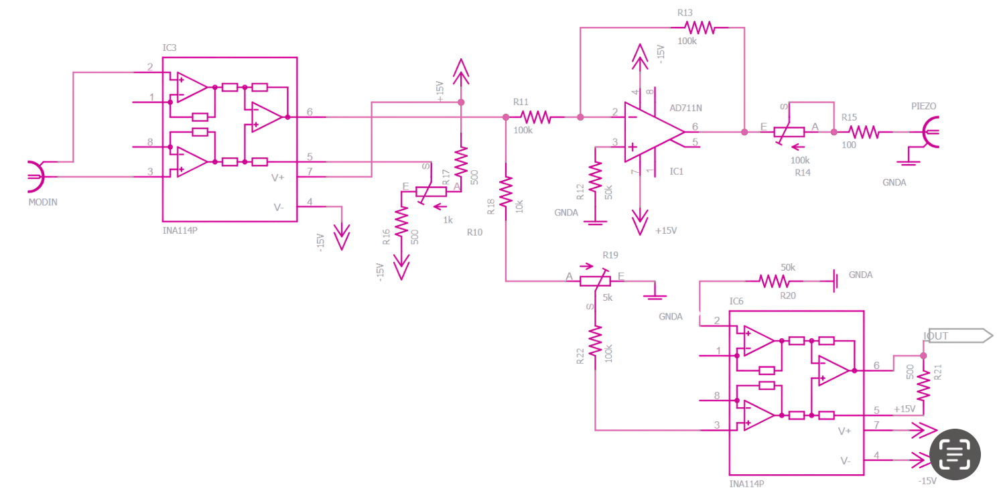
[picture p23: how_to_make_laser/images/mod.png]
            
    \end{figure}

\medskip
\newpage
\section{List of Components:}
% chktex-file 44
\begin{table}[ht]
\centering
    \begin{tabular}{|
    >{\columncolor[HTML]{ECF4FF}}l |l|l|l|}
    \hline
    \cellcolor[HTML]{F0A0D1}{\color[HTML]{000000} \textbf{Name}} &
    \cellcolor[HTML]{F0A0D1}{\color[HTML]{000000} \textbf{\#}} &
    \cellcolor[HTML]{F0A0D1}{\color[HTML]{000000} \textbf{Type}} &
    \cellcolor[HTML]{F0A0D1}\textbf{Circuit} \\ \hline
    \cellcolor[HTML]{ECF4FF}{\color[HTML]{000000} }         & 2 & 0.1 $\mu$ F       & PS              \\ \cline{2-4} 
    \cellcolor[HTML]{ECF4FF}{\color[HTML]{000000} }         & 3 & 1 $\mu$ F         & NCC, CC         \\ \cline{2-4} 
    \cellcolor[HTML]{ECF4FF}{\color[HTML]{000000} }         & 1 & 10 $\mu$ F        & NCC             \\ \cline{2-4} 
    \cellcolor[HTML]{ECF4FF}{\color[HTML]{000000} }         & 3 & 22 $\mu$ F        & CC              \\ \cline{2-4} 
    \cellcolor[HTML]{ECF4FF}{\color[HTML]{000000} }         & 1 & 33 $\mu$ F        & Switch          \\ \cline{2-4} 
    \multirow{-6}{*}{\cellcolor[HTML]{ECF4FF}{\color[HTML]{000000} Capacitor}} &
    1 &
    470 $\mu$ F &
    CC \\ \hline
    \cellcolor[HTML]{ECF4FF}                                & 3 & 100 $\Omega$      & NCC, CC, Mod    \\ \cline{2-4} 
    \cellcolor[HTML]{ECF4FF}                                & 4 & 500 $\Omega$      & CC, Mod         \\ \cline{2-4} 
    \cellcolor[HTML]{ECF4FF}                                & 3 & 3 K$\Omega$       & CC, Switch      \\ \cline{2-4} 
    \cellcolor[HTML]{ECF4FF}                                & 1 & 7,5 K$\Omega$     & CC              \\ \cline{2-4} 
    \cellcolor[HTML]{ECF4FF}                                & 3 & 10 K$\Omega$      & CC, Mod, Switch \\ \cline{2-4} 
    \cellcolor[HTML]{ECF4FF}                                & 3 & 50 K$\Omega$      & NCC, Mod        \\ \cline{2-4} 
    \multirow{-7}{*}{\cellcolor[HTML]{ECF4FF}Resistor}      & 3 & 100 K$\Omega$     & Mod             \\ \hline
    \cellcolor[HTML]{ECF4FF}                                & 2 & 1 K$\Omega$       & NCC, Mod        \\ \cline{2-4} 
    \cellcolor[HTML]{ECF4FF}                                & 1 & 5 K$\Omega$       & Mod             \\ \cline{2-4} 
    \cellcolor[HTML]{ECF4FF}                                & 1 & 10 K$\Omega$      & CC              \\ \cline{2-4} 
    \multirow{-4}{*}{\cellcolor[HTML]{ECF4FF}Potentiometer} & 1 & 100 K$\Omega$     & Mod             \\ \hline
    Rectifying diode                                        & 1 & 1N4007            & NCC             \\ \hline
    Laser diode                                             & 1 & L780P010         & Switch          \\ \hline
    Switch On/Off                                           & 1 & 100SP1T1B4M2QE    & Switch          \\ \hline
    Terminal Block                                          & 1 & MTA03\-100         & PS              \\ \hline
    \end{tabular}
\end{table}

\begin{table}[ht]
\centering
\resizebox{\textwidth}{!}{%
\begin{tabular}{|l|l|l|l|l|}
    \hline
    \rowcolor[HTML]{F0A0D1} 
    {\color[HTML]{000000} Name} &
    {\color[HTML]{000000} \#} &
    {\color[HTML]{000000} Type} &
    {\color[HTML]{000000} Circuit} &
    {\color[HTML]{000000} Datasheet} \\ \hline
    \cellcolor[HTML]{ECF4FF}{\color[HTML]{000000} } &
    1 &
    L7915ACV &
    PS &
    \url{https://www.alldatasheet.com/html-pdf/22637/STMICROELECTRONICS/L7915ACV/1622/1/L7915ACV.html} \\ \cline{2-5} 
    \multirow{-2}{*}{\cellcolor[HTML]{ECF4FF}{\color[HTML]{000000} Fixed voltage regulators}} &
    1 &
    L7815CV &
    PS &
    \url{https://www.alldatasheet.com/html-pdf/22641/STMICROELECTRONICS/L7815CV/1621/1/L7815CV.html} \\ \hline
    \cellcolor[HTML]{ECF4FF} &
    1 &
    LM337 &
    NCC &
    \url{https://www.alldatasheet.com/html-pdf/11667/ONSEMI/LM337/179/1/LM337.html} \\ \cline{2-5} 
    \multirow{-2}{*}{\cellcolor[HTML]{ECF4FF}Semiconductor} &
    1 &
    LM339 &
    CC &
    \url{https://www.alldatasheet.com/html-pdf/524807/STMICROELECTRONICS/LM339/1942/1/LM339.html} \\ \hline
    \cellcolor[HTML]{ECF4FF}NPN Transistor &
    1 &
    2N2219 &
    NCC &
    \url{https://www.alldatasheet.com/html-pdf/15066/PHILIPS/2N2219/245/1/2N2219.html} \\ \hline
    \cellcolor[HTML]{ECF4FF}Amplifier &
    2 &
    AD711N &
    CC, Mod &
    \url{https://www.alldatasheet.com/html-pdf/48159/AD/AD711/19/1/AD711.html} \\ \hline
    \cellcolor[HTML]{ECF4FF} &
    1 &
    n-channel BUZ11 &
    CC &
    \url{https://www.alldatasheet.com/html-pdf/22129/STMICROELECTRONICS/BUZ11/1619/1/BUZ11.html} \\ \cline{2-5} 
    \multirow{-2}{*}{\cellcolor[HTML]{ECF4FF}MOSFET} &
    1 &
    p-channel MTP2955 &
    Switch &
    \url{https://www.alldatasheet.com/html-pdf/5497/MOTOROLA/MTP2955/258/1/MTP2955.html} \\ \hline
    \cellcolor[HTML]{ECF4FF}R-power 50 &
    1 &
    IRF9530NS &
    CC &
    \url{https://www.alldatasheet.com/html-pdf/68327/IRF/IRF9530NS/48/1/IRF9530NS.html} \\ \hline
    \cellcolor[HTML]{ECF4FF}Instrumentation Amplifier &
    2 &
    INA114 &
    Mod &
    \url{https://www.alldatasheet.com/html-pdf/847617/TI1/INA114/53/1/INA114.html} \\ \hline
\end{tabular}
    }
\end{table}
\vfill

\begin{center}
    \begin{tikzpicture}
        \bee[cocktail,think={\small\color{black}\centering Thanks!}, bubblecolour=gray!30!white
]      
   \end{tikzpicture}
\end{center}

\end{document}

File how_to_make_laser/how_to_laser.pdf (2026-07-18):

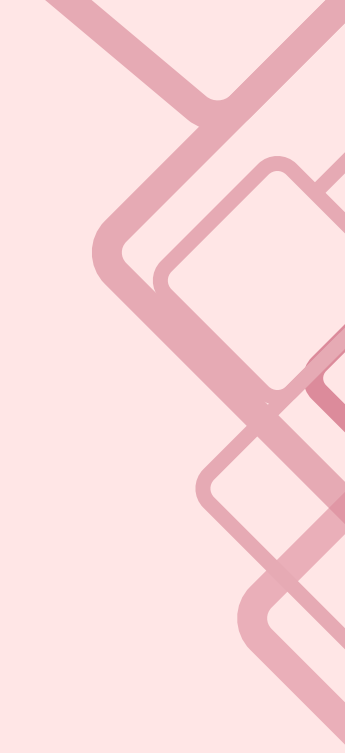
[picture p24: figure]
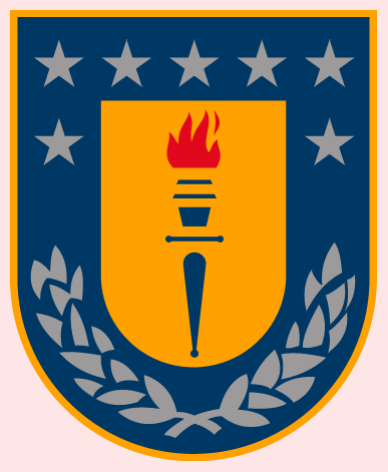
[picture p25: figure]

# How to Make Your Own Laser at Home (or in the Lab, Pretty Much the Same Thing)

## Tópicos en física II

## Florencia Fuentes Jara

# flofuentes2021@udec.cl

Universidad de Concepción
Faculty of Physical and Mathematical Sciences Department of Physics

Tópicos II
Universidad de Concepción

Florencia Fuentes
flofuentes2021@udec.cl

## Contents

1 Summary | 1
Summary | 1
2 Introduction | 1
3 Theory: The Physics Behind | 1
4 Atomic Physics Experiments | 2
5 How do we measure the linewidht of the laser: Self-Heterodyne Spectroscopy | 3
6 How Can We Build Our Own Laser? | 4
7 Optics: | 9
8 Results | 10
9 Conclusion | 10
References | 11
APPENDIX | 12
A Circuit Diagrams NCC: | 12
B List of Components: | 14

## 1 Summary

This project presents a comprehensive guide to designing and constructing an in house laser system suitable for atomic physics experiments. This report details the theoretical foundations of laser operation, practical electronics design, hands-on construction techniques, and methods for spectral linewidth narrowing. Our goal is to use them for laser cooling and trapping of alkali atoms, particularly Rubidium 85 and 87.

## 2 Introduction

Lasers have revolutionized modern physics, enabling unprecedented control over atomic and molecular systems. This report documents the development of a custom laser system design for atomic physics experiments, specifically targeting applications in laser cooling and magneto-optical trapping (MOT). The motivation arises from the need for affordable, customizable laser sources in research and education settings. We present a step-by-step approach to laser construction, from basic electronic components to advanced optical feedback techniques.

## 3 Theory: The Physics Behind

### 3.1 What is a Laser?

A laser (Light Amplification by Stimulated Emission of Radiation) is a device that generates coherent, monochromatic, and highly directional light through the process of stimulated emission. Unlike conventional light sources that emit radiation through spontaneous emission (resulting in incoherent, polychromatic light), lasers produce light waves that are in phase both temporally and spatially.

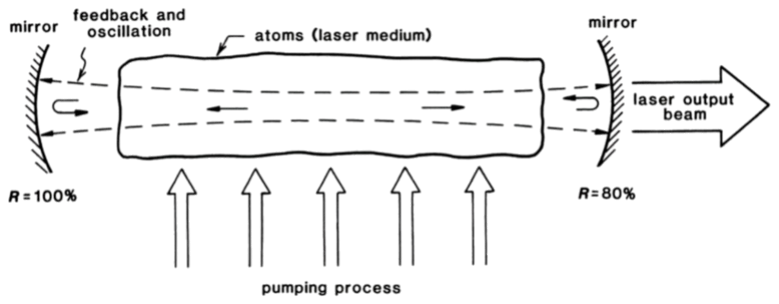
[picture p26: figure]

- Stimulated Emission: When an atom or molecule in an excited state encounters a photon with energy equal to the transition energy to a lower state, it can be stimulated to emit a second photon identical in frequency, phase, polarization, and direction to the incident photon.
- Population Inversion: For stimulated emission to dominate over absorption, more atoms must occupy the excited state than the ground state a condition known as population inversion. This non-thermal equilibrium state is achieved through pumping, where external energy (electrical, optical, or other forms) excites the gain medium.
- Optical Feedback: An optical resonator (typically formed by two mirrors) provides positive feedback, allowing photons to make multiple passes through the gain medium, stimulating further emission. One mirror is partially transmissive, allowing a fraction of the amplified light to escape as the laser beam.

Some essential characteristics of lasers are: coherence, monochromaticity, directivity, and brightness.

### 3.2 Why Do We Need Them For?

In our case we will use Laser diodes due to their compactness, efficiency, direct electrical pumping, compatibility with specific atomic transitions such as Rubidium D-lines at 780 nm and 795 nm, tunability, and cost-effectiveness for laboratory use.

The external cavity configuration we employ enhances the basic laser diode’s performance by narrowing its linewidth and in near future enabling mode-hop-free tuning, making it suitable for precision spectroscopy and laser cooling experiments.

## 4 Atomic Physics Experiments

Lasers have changed experimental atomic physics by allowing precise spectroscopy and control of atomic systems. They are essential for exploring quantum phenomena, testing nature’s symmetries, and advancing quantum technologies. This section discusses lasers’ roles in measuring and manipulating atomic systems, focusing on alkali atoms and cold atoms.

### 4.1 Alkali Atoms: Rubidium 85 and 87

Rubidium is a soft, ductile alkali metal, composed naturally of two stable isotopes, 85Rb and 87Rb, in the following ratio; 72.15 % corresponds to 85Rb and 27.85 % to 87Rb. The D2 line of Rubidium 85 and 87 has a natural linewidth (FWHM) of 6.07 MHz [1, 2], which is the transition we will use for cooling and trapping atoms in a Magneto Optical Trap (MOT).


Figure 1: Rubidium 85 and 87 D2 transition hyperfine structure, with frequency splittings between the hyperfine energy levels.

### 4.2 Laser Cooling and Trapping of Atoms

Laser cooling uses light-matter momentum transfer to slow atomic motion, achieving temperatures as low as microkelvin. In Doppler cooling, the foundational technique, counterpropagating laser beams tuned slightly below an atomic resonance (e.g., Rb-87’s D2 line at 780 nm) create a velocity-dependent damping force that reduces kinetic energy [3]. This cooling enables optical molasses, where atoms scatter photons cyclically, reaching temperatures near the Doppler limit TD =

ℏΓ
2kB

[4].

### 4.3 Magneto-Optical Trap (MOT)

For trapping, magneto-optical traps (MOTs) combine laser cooling with quadrupole magnetic fields to confine atoms at densities up to 10⁸atoms/cm³
[5]. The MOT uses six laser beams arranged symmetrically around the trap center, tuned to the red of the atomic resonance, and a magnetic field gradient to create a restoring force that arises from Zeeman shift enhanced scattering in regions of non-zero field gradient, creating a net restoring force toward the trap center. Radiation pressure from the lasers balances this force, enabling stable, long-term confinement of ultracold atomic ensembles [6].
Critical to both Doppler cooling and MOT confinement is precise laser linewidth stability (∆ν < Γ ≈ 6 MHz for Rb-87) and intensity control. Narrow linewidth ensures resonant photon scattering for efficient momentum transfer, while stabilized intensity maximizes scattering rates without causing excessive heating or loss of atoms. Achieving these requirements necessitates advanced laser systems, often involving external cavity configurations and optical feedback techniques.

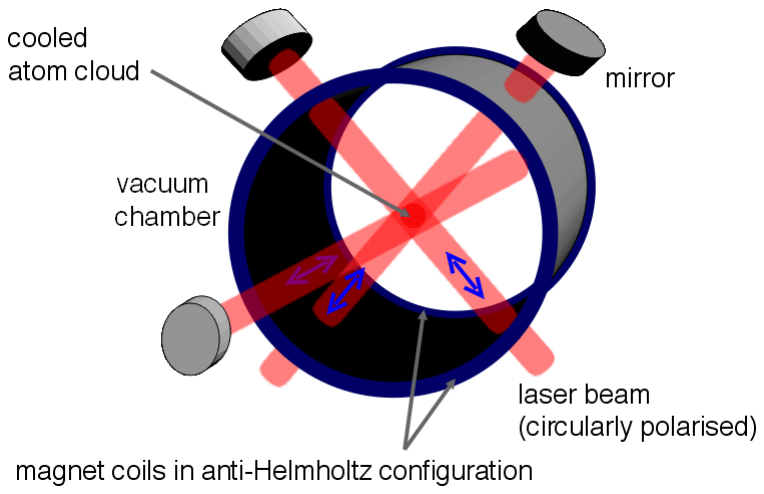
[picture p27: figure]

Figure 2: Magneto-Optical Trap (MOT) setup [7].

## 5 How do we measure the linewidht of the laser: Self-Heterodyne Spectroscopy

To measure the linewidth of our laser system, we employ self-heterodyne spectroscopy, a technique based on the Wiener-Khintchine theorem. This method involves splitting the laser beam into two paths—one delayed by a time τ relative to the other—and then recombining them on a photodetector. The interference pattern yields the power spectral density (PSD), which reveals the laser’s coherence properties.

Power Spectral Density Function: The PSD derived from the Wiener-Khintchine theorem for our setup is:

S(ω, τ ) =

1/2 P

2/0 τc
1 + ω ± Ω

2
τ

2
c

n
1 − e

−

−|τ|
τc [cos(ω ± Ω)]τ

o
+

sin(ω ± Ω)|τ |
(ω ± Ω)τc

+

1
2

P

2
0 πe

−

−|τ|
τc δ(ω±Ω)

(1)
where τc is the coherence time, Ω is the frequency shift from an acousto-optic modulator (AOM), and P0 is the laser power. This model predicts two regimes: when τ ≫ τc, the spectrum collapses to a pure Lorentzian; when τ ≪ τc, it shows a narrow delta function peak. Achieving sub-MHz linewidths typically requires fiber delays of tens of kilometers, which is impractical for most laboratories. Our approach uses optical feedback to achieve narrow linewidths without such long delays [8].


Figure 3: Simulation of the power spectral density model in different regimes of coherence. The transition from coherent to incoherent interference is evident as the delay time increases relative to the coherence time.

## 6 How Can We Build Our Own Laser?

The steps involved in creating a functional laser system are described in this section. It covers choosing components, circuit design, optical alignment, and optimization methods. The method seeks to address particular requirements for atomic physics experiments and emphasizes the integration of theory and practice.

### 6.1 Electronics

Electronic control systems are vital for stable laser systems, focusing on current regulation, temperature stabilization, and frequency locking. Key circuits include the current driver, temperature stabilization, and lock-in amplifier for reliable atomic physics experiments.[9]

### 6.1.1 Basic Components: Resistance, Capacitance, Inductance

Electronic circuits for laser control utilize three fundamental passive components:

- Resistors: The characteristic by which it oppose the flow of current is known as resistance. The resistance of a resistor is denoted by symbol R and measured in Ohms (Ω). The typical circuit symbol of a resistor is shown in the following figure.

Resistors are used to set operating current and signal levels in circuits, provide voltage reduction, set precise gain values in precision circuits, act as shunts in ammeters and voltage meters, behave like damping agents in oscillators and timer circuits, act as bus and line terminators in digital circuits, provide feedback networks for amplifiers, and act as pull up and pull down elements in digital circuits.

OHM’s Law:
The linear relationship between voltage (V ), current (I), and resistance (R):
V = IR | (2)

This equation rule the current flow through resistive elements, allowing us to calculate voltage drops, power dissipation (P = I

2R = V

2/R).

- Capacitors: Their major function is simple energy storage, where charge from an applied current is stored within the capacitor and later released back into the circuit as useful current. The rate of charging and discharging can be controlled by placing a resistor in series with the capacitor. This effect is often used in high-current discharge circuits, as well as small energy backup supplies for low-power memory Integrated circuits(ICs). It is also used to smooth out power supply ripple, control timing in ICs, and alter the shape of waveforms.
- Inductors: The inductor is basically a wire of finite length twisted into a coil and has a property, known as inductance, which oppose any change in the electric current.

Inductance: The voltage across an inductor is proportional to the rate at which the current changes. The relationship between voltage and current are described by the following equations:

VL = L

dIL
dt | (3)

IL =

1
L

Z
VL | (4)

### 6.1.2 Active components

Active components control current flow and amplify signals using external power sources, enabling precise laser regulation.

- Semiconductors: A semiconductor is a material whose electrical conductivity lies between a conductor and an insulator. This unique property makes semiconductors ideal for controlling electrical current, enabling their use in a wide range of electronic devices.

– Diodes: A two-lead semiconductor device that acts as a one-way gate to electric current flow. When a diode’s anode lead is made more positive in voltage than its cathode lead the condition is referred to as forward biasing so the current is permitted to flow through the device.

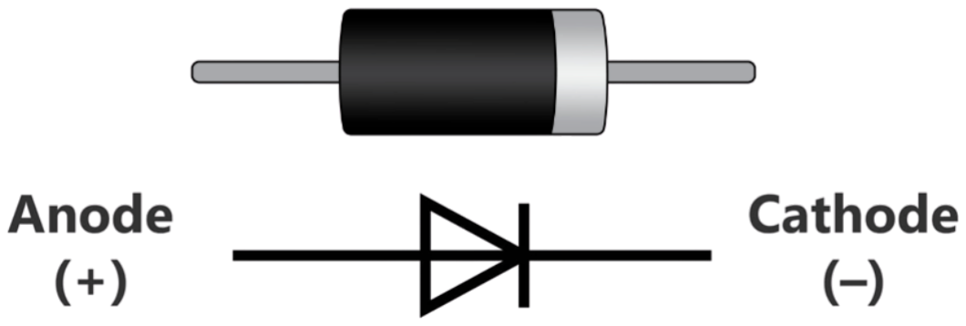
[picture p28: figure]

– Transistors: Three-terminal semiconductor devices that amplify or switch electronic signals. Bipolar Junction Transistors (BJTs) are current-controlled and excel
in linear, low-noise applications like current regulators, while Metal-Oxide-Semiconductor Field-Effect Transistors (MOSFETs) are voltage-controlled and offer fast switching with minimal gate current, ideal for pulse-width modulation (PWM) in temperature controllers.


- Amplifiers: They are essential circuits for increasing signal amplitude while preserving signal integrity, playing critical roles in laser control systems for error signal processing, photodetector signal conditioning, and driving control elements.

– Operational Amplifiers: Op amps are high gain differential amplifiers with two inputs (inverting and non-inverting) and a single output. In ideal behavior, they have infinite open loop gain, infinite input impedance, zero output impedance, and infinite bandwidth. Real op amps approach these ideals with specifications tailored to specific applications.


Gain: The amplification factor of a circuit, defined as the ratio of output to input signal. For voltage amplifiers, Av = Vout/Vin; in decibels, GdB = 20 log10(Av). Determines sensitivity of feedback loops and must be optimized for stability versus response speed.

– Instrumental Amplifiers: INAmp is a high precision differential amplifier designed to amplify small signals from sensors while rejecting common mode noise, featuring high input impedance, high gain, and excellent common mode rejection ratio (CMRR).

### 6.1.3 Low and high pass filters:

Low-pass and high-pass filters are essential for controlling a signal’s frequency content. A low-pass filter allows low-frequency signals to pass through while reducing the amplitude of higher-frequency signals, and a high-pass filter does the opposite, allowing high frequencies to pass through while blocking low-frequency components.


Figure 4: The low and high-pass versions of the RL and RC circuits. Vs(w) is the voltage of the function generator and Vo(w) is the voltage on the oscilloscope.

Impedance (Z): generalizes resistance to AC circuits, representing the total opposition a circuit presents to alternating current flow. While resistance dissipates energy as heat, impedance includes both resistive and reactive components which store and release energy without dissipation. In complex notation, Z = R + jX, where X is the reactance that depends on frequency: capacitive reactance XC = −1/(ωC) decreases with frequency, while inductive reactance XL = ωL increases.

### 6.2 Optoelectronics: Laser Diodes

Laser diodes are light emitting diodes with two “mirrors” on the surface of the diode to create a laser cavity. When the diode is forward biased, charges are injected into the active area of the junction, while electrons and holes recombine in the junction, creating spontaneous emission of photons. These photons can cause other electron hole pairs to recombine by stimulated emission. When the current is high enough, the device lases.[10]

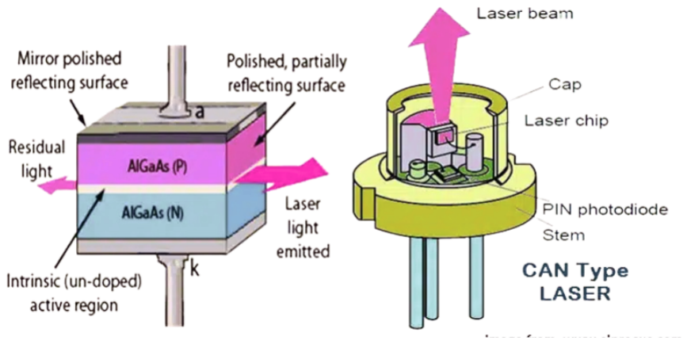
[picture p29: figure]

### 6.3 Hands-On Construction

The electronic control system is constructed from four independent but interconnected circuits, each addressing a specific aspect of laser stabilization. All circuits are built on custom designed printed circuit boards (PCBs) to minimize noise, improve reliability, and facilitate troubleshooting.

### 6.3.1 Negative Current Control Circuit:

The laser diode driver requires precise, low noise current regulation. We implement a negative feedback current controller¹
that maintains constant current despite fluctuations in diode voltage and temperature.

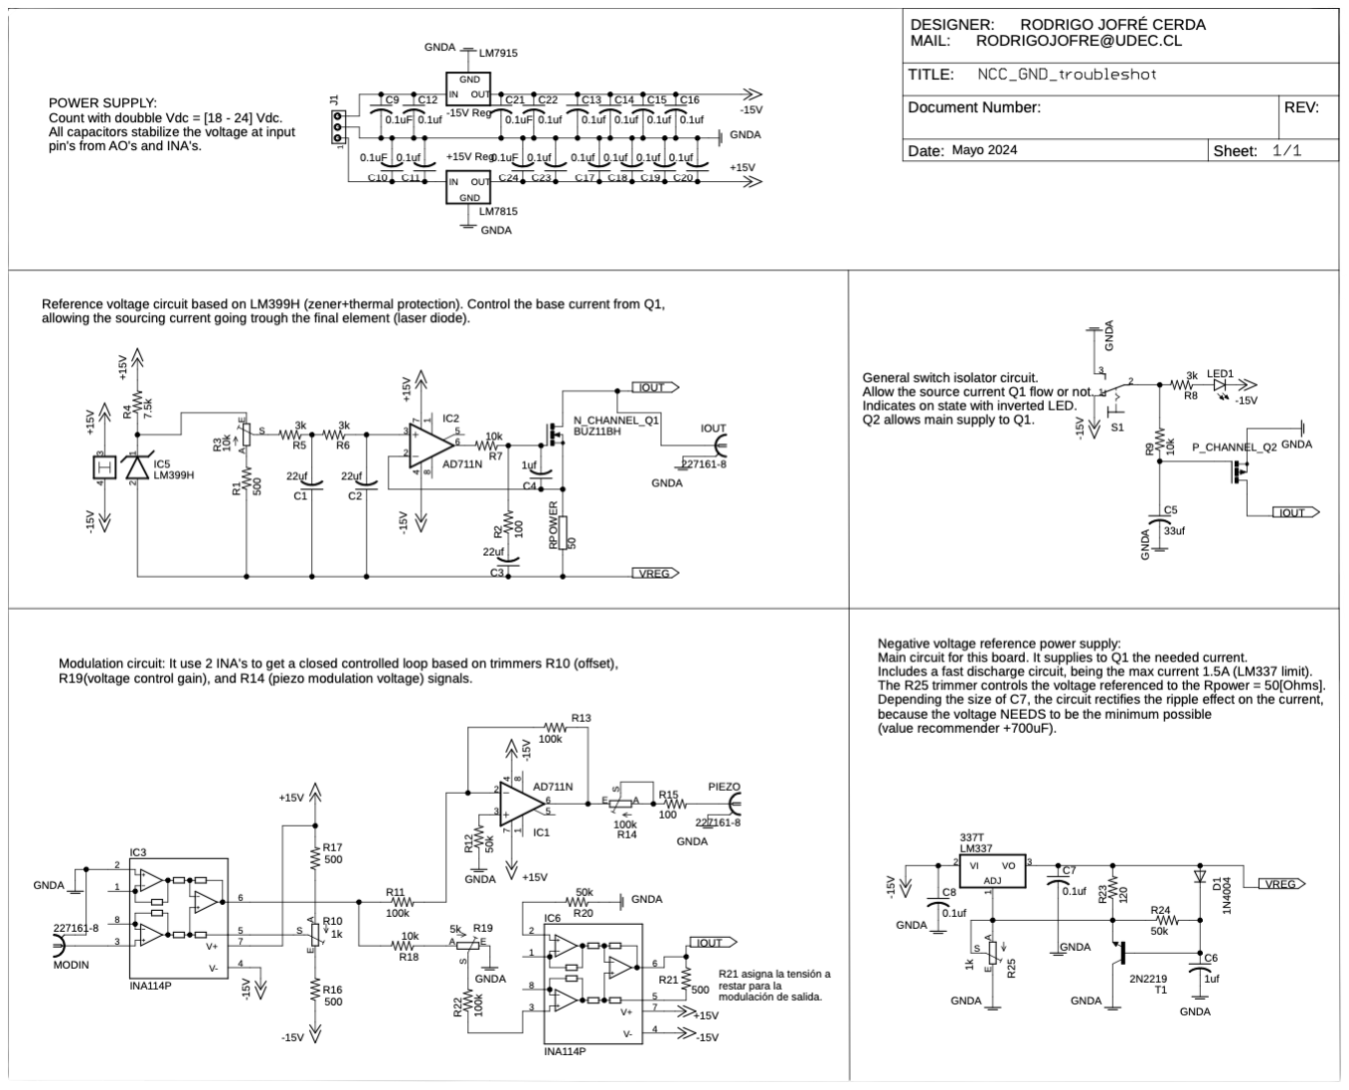
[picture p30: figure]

### 6.3.2 Thermoelectric Circuit:

Temperature stabilization is critical for wavelength control, as diode wavelength shifts approximately 0.3 nm/◦C. We designed a thermoelectric cooler (TEC) controller using a dual operational amplifier configuration. The first stage amplifies the voltage difference between a thermistor and a reference voltage, producing an error signal. The second stage, with adjustable gain, drives the TEC to maintain the laser diode at a constant temperature. The circuit includes protection diodes to prevent reverse current and large capacitors to stabilize the control voltage.

1For more details of the ncc circuit see APPENDIX 9


Figure 5: Thermoelectric control circuit.

### 6.3.3 PID controller circuit:

The PID circuit is often utilized as a control loop feedback controller. The letters making up the acronym PID correspond to Proportional (P), Integral (I), and Derivative (D), which represents the three control settings of a PID circuit. The PID circuit actively controls the system so as to hold it at the set point by generating an error signal that is essentially the difference between the set point and the current value. The three controls relate to the time-dependent error signal.


Figure 6: PID controller circuit.

### 6.3.4 Lock-in Circuit:

This circuit extracts the error signal from reflected laser light by mixing it with a reference modulation frequency.


Figure 7: Lock-in amplifier circuit

### 6.3.5 PCB Design and Soldering:

All circuits were fabricated on custom-designed printed circuit boards (PCBs) to minimize noise and ensure reliability. Soldering was performed using a temperature-controlled soldering iron with proper flux application. Sensitive components like the laser diode were soldered quickly to prevent thermal damage.

## 7 Optics:

### 7.1 Optical elements

Our laser system employs several key optical components:

- Diffraction grating: is an optical device exploiting the phenomenon of diffraction. It contains a periodic structure, which causes spatially varying optical amplitude and/or phase changes.[11]
- Beam splitter: They separate incident light into two or more beams of the same wavelength.
- Acusto-Optic Modulator(AOM): is a device which can be used for controlling the transmitted power of a laser beam with an electrical drive signal.[12]
- Piezoelectric transducer (PZT): For fine adjustment of grating angle, the crystals produce a pressure when deformed by an applied voltage and produce a voltage when deformed by an applied pressure
- Photodetectors: Sensors that convert incident light into measurable electrical signals.

### 7.2 Narrowing the Linewidth

### 7.2.1 External Cavity in a Laser Diode:

We extended the laser cavity externally by adding a diffraction grating, which provides wavelength selective feedback. The external cavity length increases the photon lifetime in the cavity, effectively narrowing the linewidth.

### 7.2.2 Optical Feedback:

Controlled optical feedback from the diffraction grating narrows the linewidth through regenerative amplification. We optimized the feedback ratio to approximately 10−30 % of the output power. Too little feedback provides insufficient narrowing, while too much can cause instability or mode hops.

### 7.3 Experimental Setup

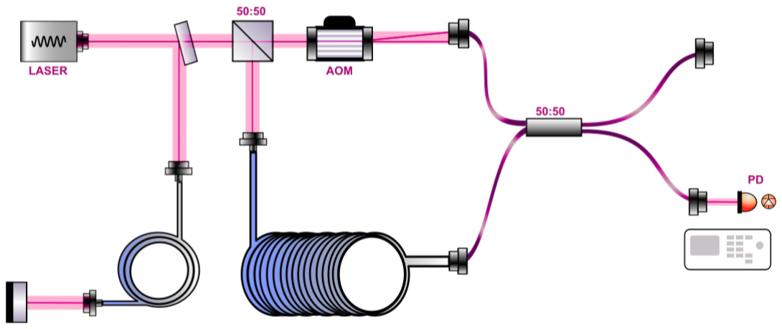
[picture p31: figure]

Figure 8: Schematic representation of the experimental setup for feedback stabilized diode laser.

## 8 Results

We successfully constructed and characterized our in-house laser system, focusing on linewidth reduction through optical feedback stabilization. The performance was quantified using self-heterodyne spectroscopy with a fiber delay, allowing precise measurement of the laser’s power spectral density (PSD) and coherence time.


(a) Without feedback | (b) Width feedback

Figure 9: Measured power spectral density (PSD).

The coherence time τc increased from 2.1×10⁻⁷

s (without feedback) to 4.03×10⁻⁵ s (with
feedback), corresponding to coherence lengths of 63 m and 12.1 km, respectively. This dramatic improvement enables precise spectroscopy of rubidium’s hyperfine transitions.

## 9 Conclusion

We have successfully designed, constructed, and characterized an in-house, low-cost, optically feedback stabilized diode laser system suitable for atomic physics experiments. Our work demonstrates that resource constrained laboratories can develop high performance laser systems through careful design and integration of commercial components. Future work will focus on integrating the laser into a complete magneto-optical trap system.

Bye!

## References

[1] Daniel Steck. Rubidium 85 D Line Data. url: https://steck.us/alkalidata/rubidi um85numbers.pdf. (https://steck.us/alkalidata/rubidium85numbers.pdf)
[2] Daniel Steck. Rubidium 87 D Line Data. url: https://steck.us/alkalidata/rubidi um87numbers.pdf. (https://steck.us/alkalidata/rubidium87numbers.pdf)
[3] Christopher J Foot. Atomic physics. Oxford ; New York: Oxford University Press, 2005. isbn: 9780198506959.
[4] Harold J Metcalf and Peter Van der Straten. Laser Cooling and Trapping. Springer Science & Business Media, Dec. 2012. isbn: 9781461214700.
[5] William D. Phillips. “Nobel Lecture: Laser cooling and trapping of neutral atoms”. In: Reviews of Modern Physics 70.3 (July 1998), pp. 721–741. doi: https://doi.org/10.1103/revmodphys.70.721 2. (https://doi.org/https://doi.org/10.1103/revmodphys.70.721)
[6] E. L. Raab et al. “Trapping of Neutral Sodium Atoms with Radiation Pressure”. In: Phys. Rev. Lett. 59 (23 Dec. 1987), pp. 2631–2634. doi: 10.1103/PhysRevLett.59.2631 2. (https://doi.org/10.1103/PhysRevLett.59.2631) url: https://link.aps.org/doi/10.1103/PhysRevLett.59.2631.
[7] Wikimedia Commons. File:MOT setup.png — Wikimedia Commons, the free media repository. 2022. url: https://commons.wikimedia.org/w/index.phptitle=File:MOT_setup.png&oldid=706881704. (https://commons.wikimedia.org/w/index.phptitle=File:MOT_setup.png&oldid=706881704)
[8] L. Richter et al. “Linewidth determination from self-heterodynemeasurements with subcoherence delay times”. In: IEEE Journal of Quantum Electronics 22.11 (1986), pp. 2070– 2074. doi: 10.1109/JQE.1986.1072509 2. (https://doi.org/10.1109/JQE.1986.1072509)
[9] Paul Scherz and Simon Monk. Practical Electronics for Inventors. 4th ed. McGraw Hill TAB, Apr. 2016. isbn: 978-1259587542.
[10] R. Paschotta. Laser Diodes. RP Photonics Encyclopedia. Available online at https : //www.rp- photonics.com/laser_diodes.html. (https://www.rp-photonics.com/laser_diodes.html) 2005. doi: 10.61835/m3d 2. (https://doi.org/10.61835/m3d) url: https://www.rp-photonics.com/laser_diodes.html (visited on 02/05/2026).
[11] R. Paschotta. Diffraction Gratings. RP Photonics Encyclopedia. Available online at htt ps://www.rp-photonics.com/diffraction_gratings.html. 2013. doi: 10.61835/5ch
2. (https://doi.org/10.61835/5ch) url: https://www.rp- photonics.com/diffraction_gratings.html (https://www.rp-photonics.com/diffraction_gratings.html) (visited on 02/05/2026).
[12] R. Paschotta. Acousto-optic Modulators. RP Photonics Encyclopedia. Available online at https://www.rp-photonics.com/acousto_optic_modulators.html. 2019. doi: 10.61 835/az1 2. (https://doi.org/10.61835/az1) url: https://www.rp-photonics.com/acousto_optic_modulators.html (visited on 02/05/2026).

# APPENDIX

## A Circuit Diagrams NCC:

A.1 Controlled dual power source (PS):

This setup uses two reference voltages to send the right amount of current to the Peltier system, which helps control the temperature.The circuit can provide strong output power. Each IC5 and IC6, which are integrated circuits, can handle up to 1.5A of current, or 3A total for the whole circuit, when the voltage is 18 volts direct current.Capacitors are included to keep the voltage signals steady for the main ICs in the industrial control system.

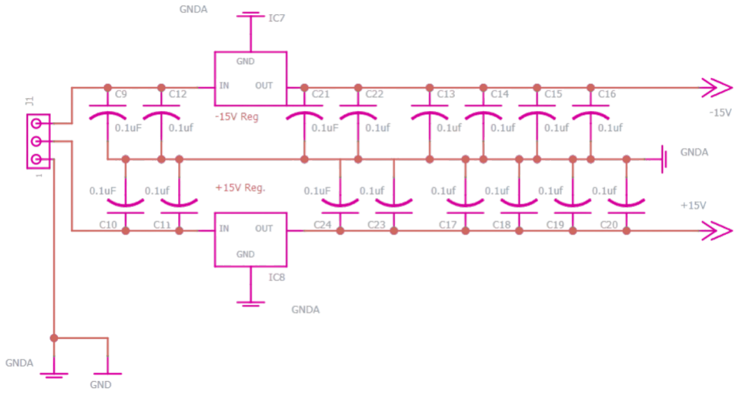
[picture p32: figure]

A.2 Controlled negative power source (NCC):

The negative voltage control is the most important aspect of our circuit. Because the laser needs a precise negative voltage to function correctly, this setup is essential. The LM337 regulator enables us to continuously vary the voltage between -1.2 V and -37 V. To prevent fluctuations, we also employ an NPN transistor with a rectifier diode, as well as a potentiometer for precise tuning. Input and output capacitors are also included to reduce noise and stabilize the current. This system maintains a steady voltage for the laser, avoiding instabilities that might impair the quality of the produced beam."

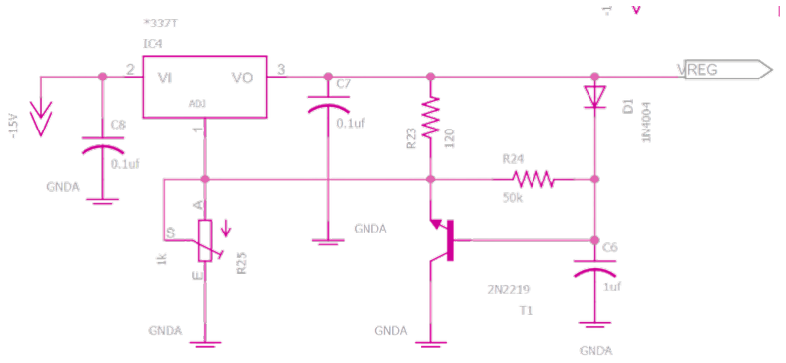
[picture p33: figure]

A.3 Current control circuit (CC):

Current management is another essential component of laser operation. We employ an LM399Hbased circuit for this purpose, a high-stability, low-noise Zener diode utilized for accurate voltage references. Plus, we use an AD711N operational amplifier to compare the input voltage to a set reference, which helps to keep the laser’s power supply current within ideal limits. The voltage-to-current conversion is regulated by a MOSFET, which serves as the control element, in order to avoid overloads and variations. This circuit helps us minimize signal noise, which is critical for achieving a high-quality, stable laser for spectroscopy.

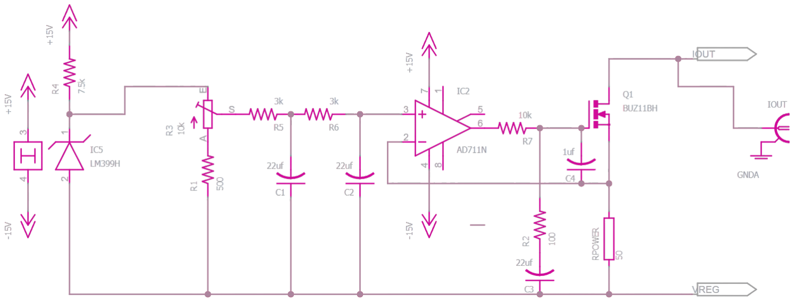
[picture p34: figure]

A.4 General control circuit (Switch):

This circuit enables to on/off the laser and is the last checkup before damaging the laser diode.

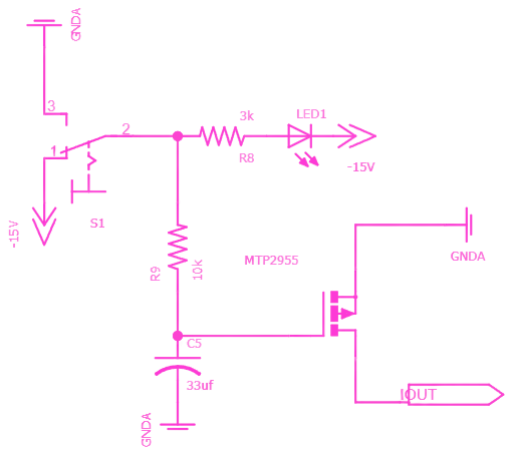
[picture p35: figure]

A.5 Modulation circuit (Mod):

We implemented a modulation system that enables us to control the output power while simultaneously maintaining the beam frequency in order to enhance laser performance. Voltage modulation of the laser enables precise control over its intensity. Additionally, the laser’s optical cavity is dynamically controlled by a piezoelectric element-based stabilization system. This system is especially helpful in spectroscopic applications, where it is essential to maintain beam coherence and avoid jumps that could compromise the precision of the measurement."

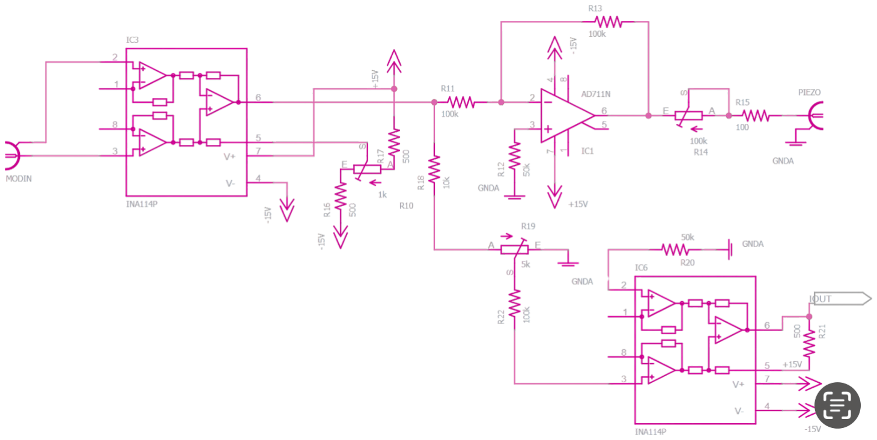
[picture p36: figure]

## B List of Components:

Name | # | Type | Circuit
Capacitor | 2 | 0.1 µ F | PS
| 3 | 1 µ F | NCC, CC
| 1 | 10 µ F | NCC
| 3 | 22 µ F | CC
| 1 | 33 µ F | Switch
| 1 | 470 µ F | CC
Resistor | 3 | 100 Ω | NCC, CC, Mod
| 4 | 500 Ω | CC, Mod
| 3 | 3 KΩ | CC, Switch
| 1 | 7,5 KΩ | CC
| 3 | 10 KΩ | CC, Mod, Switch
| 3 | 50 KΩ | NCC, Mod
| 3 | 100 KΩ | Mod
| 2 | 1 KΩ | NCC, Mod
| 1 | 5 KΩ | Mod
| 1 | 10 KΩ | CC Potentiometer
| 1 | 100 KΩ | Mod
Rectifying diode | 1 | 1N4007 | NCC
Laser diode | 1 | L780P010 | Switch
Switch On/Off | 1 | 100SP1T1B4M2QE | Switch
Terminal Block | 1 | MTA03100 | PS
Name | # | Type | Circuit | Datasheet
| 1 1 | L7915ACV L7815CV | PS PS | https://www.alldatasheet.com/html-pdf/22637/STMICROELECTRONICS/L7915ACV/1622/1/L7915ACV.html Fixed voltage regulators https://www.alldatasheet.com/html-pdf/22641/STMICROELECTRONICS/L7815CV/1621/1/L7815CV.html
| 1 1 | LM337 LM339 | NCC CC | https://www.alldatasheet.com/html-pdf/11667/ONSEMI/LM337/179/1/LM337.html Semiconductor https://www.alldatasheet.com/html-pdf/524807/STMICROELECTRONICS/LM339/1942/1/LM339.html
NPN Transistor | 1 | 2N2219 | NCC | https://www.alldatasheet.com/html-pdf/15066/PHILIPS/2N2219/245/1/2N2219.html
Amplifier | 2 | AD711N | CC, Mod | https://www.alldatasheet.com/html-pdf/48159/AD/AD711/19/1/AD711.html
| 1 1 | n-channel BUZ11 p-channel MTP2955 | CC Switch | https://www.alldatasheet.com/html-pdf/22129/STMICROELECTRONICS/BUZ11/1619/1/BUZ11.html MOSFET https://www.alldatasheet.com/html-pdf/5497/MOTOROLA/MTP2955/258/1/MTP2955.html
R-power 50 | 1 | IRF9530NS | CC | https://www.alldatasheet.com/html-pdf/68327/IRF/IRF9530NS/48/1/IRF9530NS.html
Instrumentation Amplifier | 2 | INA114 | Mod | https://www.alldatasheet.com/html-pdf/847617/TI1/INA114/53/1/INA114.html

Thanks!

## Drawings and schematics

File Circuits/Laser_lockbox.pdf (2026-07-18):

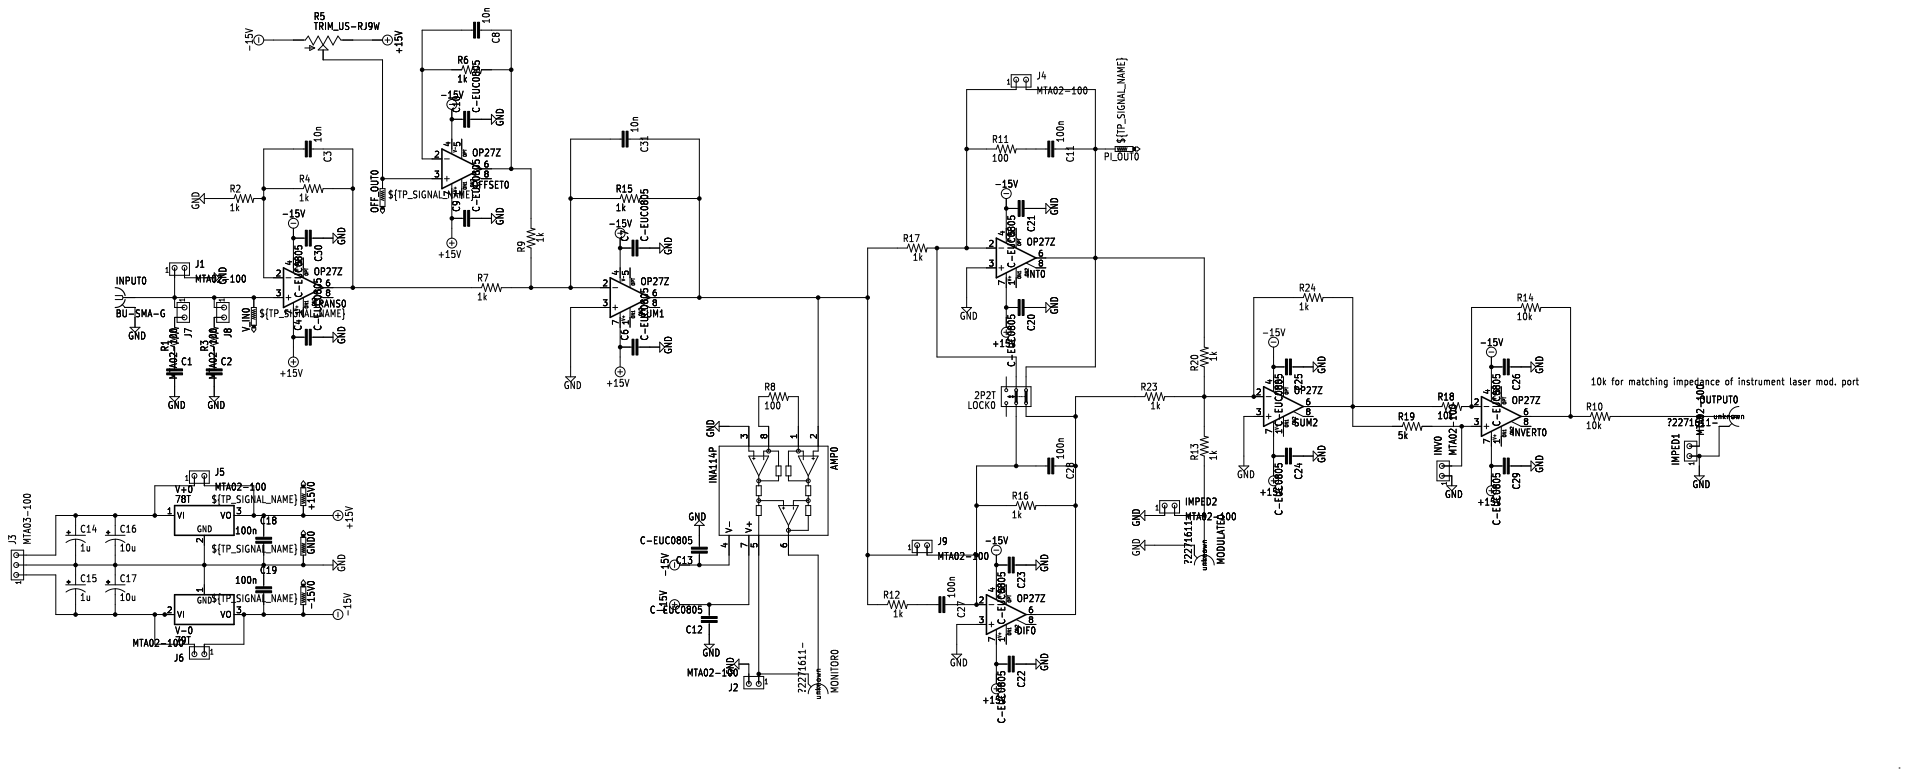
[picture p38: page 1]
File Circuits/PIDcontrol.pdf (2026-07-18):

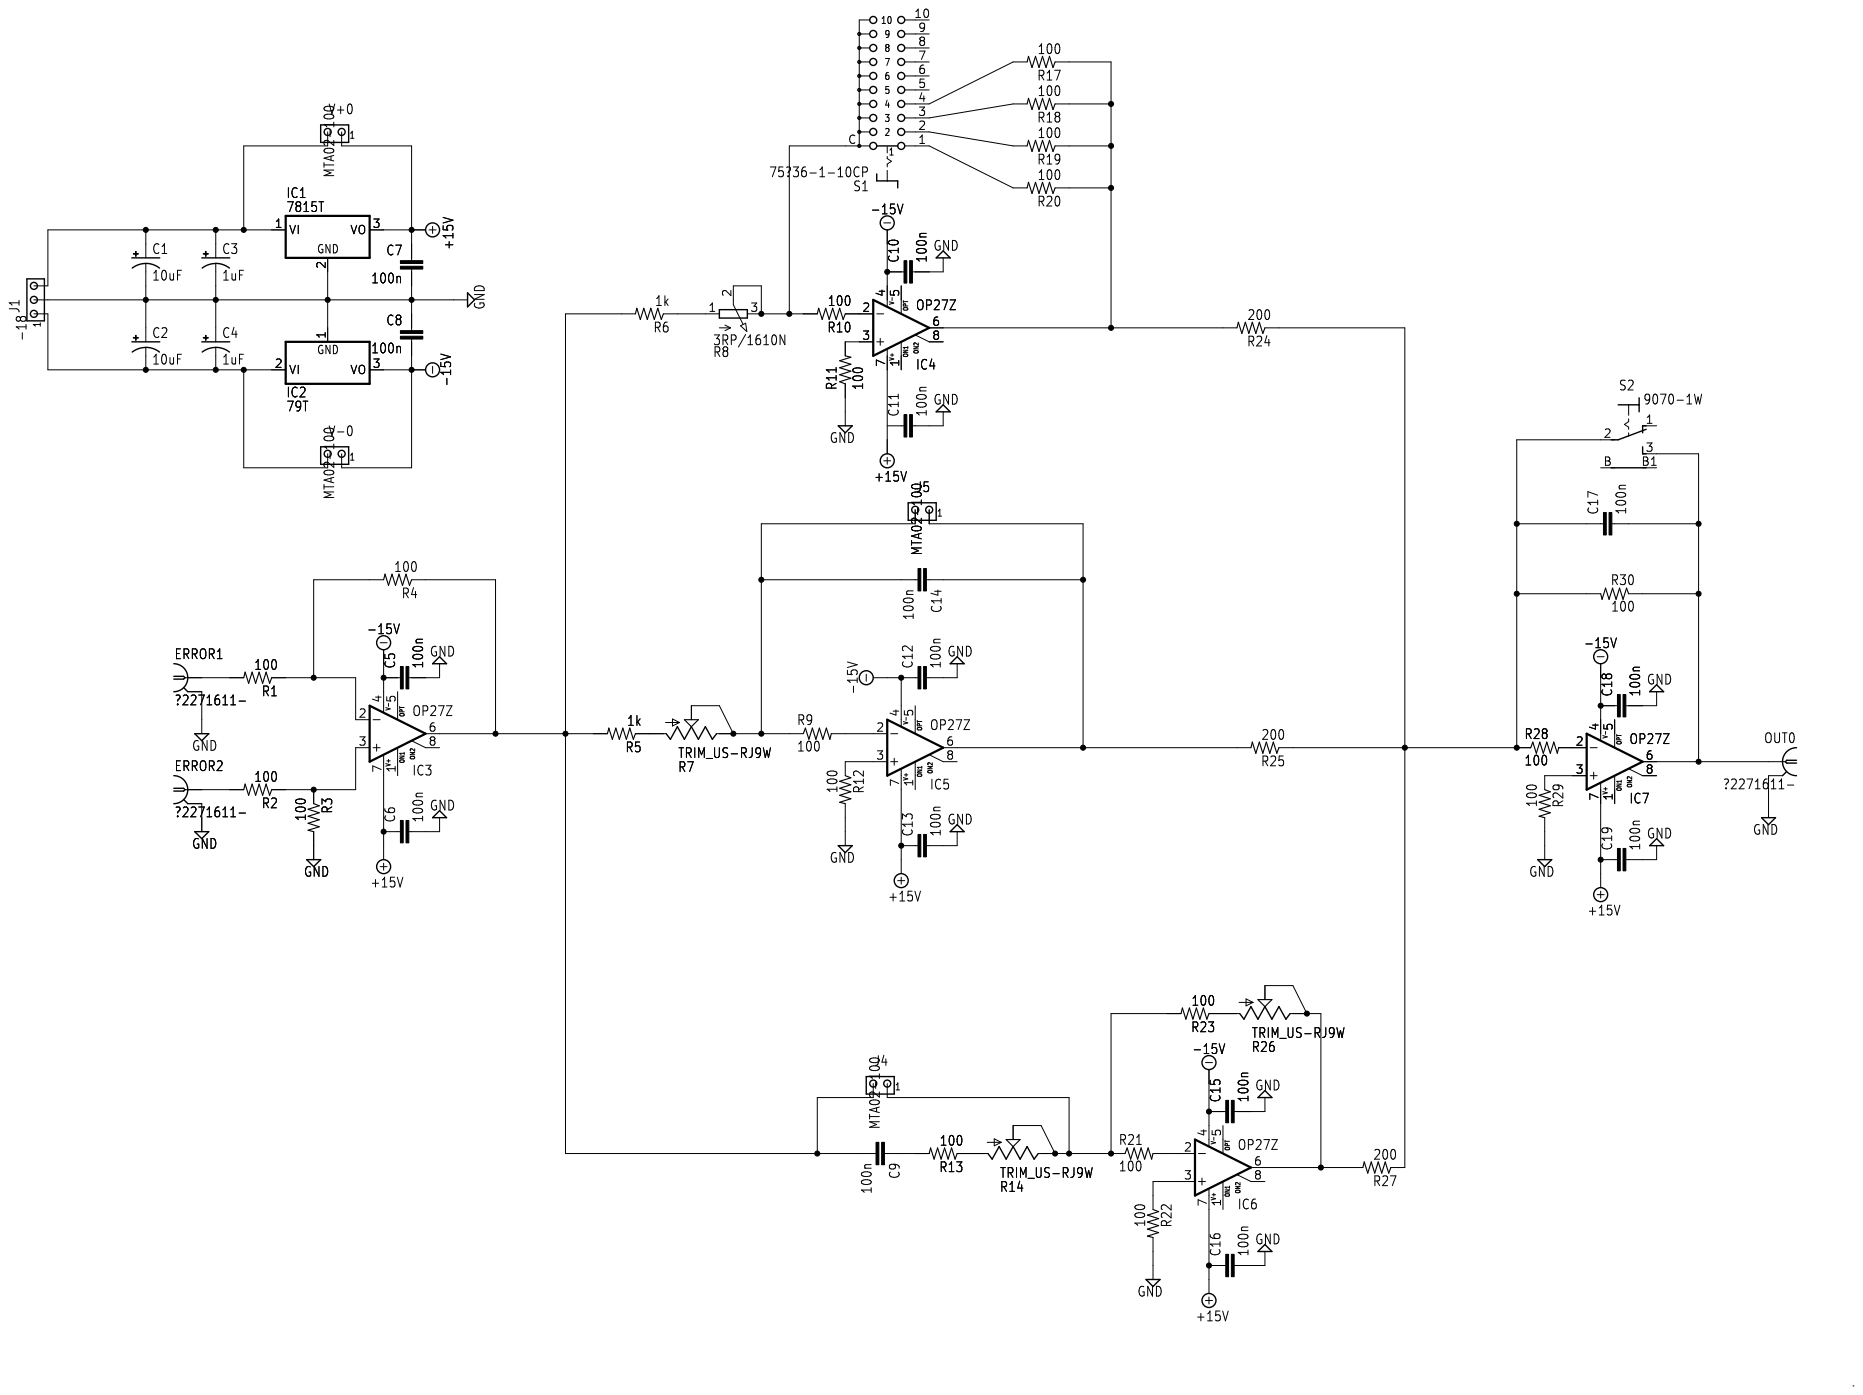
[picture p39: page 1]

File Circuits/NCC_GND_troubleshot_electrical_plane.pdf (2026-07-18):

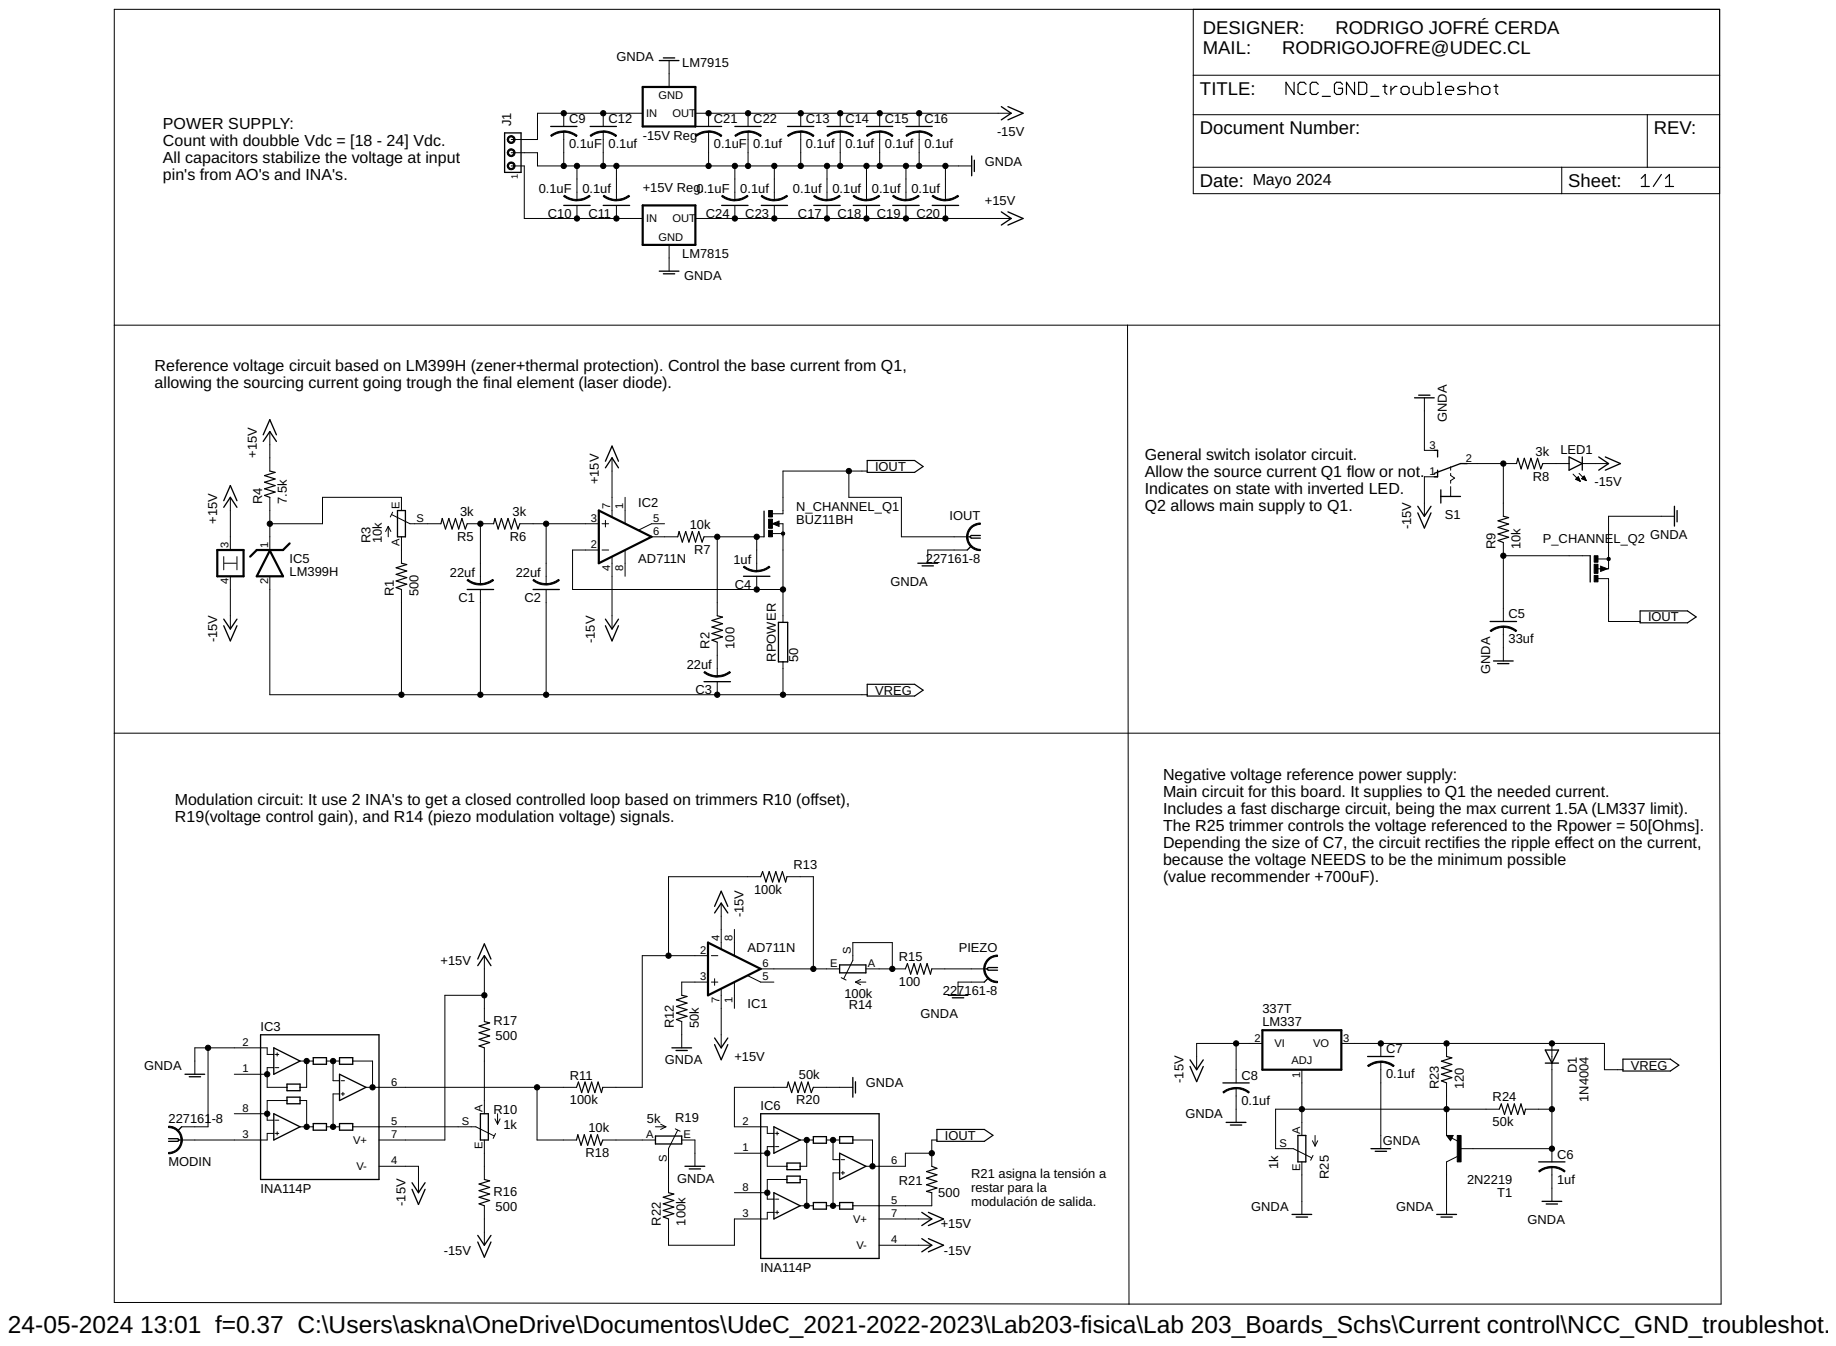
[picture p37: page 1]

POWER SUPPLY: Count with doubble Vdc = [18 - 24] Vdc. All capacitors stabilize the voltage at input pin's from AO's and INA's.

Indicates on state with inverted LED. Q2 allows main supply to Q1.

Modulation circuit: It use 2 INA's to get a closed controlled loop based on trimmers R10 (offset), R19(voltage control gain), and R14 (piezo modulation voltage) signals. | Negative voltage reference power supply: Main circuit for this board. It supplies to Q1 the needed current. Includes a fast discharge circuit, being the max current 1.5A (LM337 limit). The R25 trimmer controls the voltage referenced to the Rpower = 50[Ohms]. Depending the size of C7, the circuit rectifies the ripple effect on the current, because the voltage NEEDS to be the minimum possible (value recommender +700uF). 337T

R21 asigna la tensión a
restar para la modulación de salida.

24-05-2024 13:01 f=0.37 C:\Users\askna\OneDrive\Documentos\UdeC_2021-2022-2023\Lab203-fisica\Lab 203_Boards_Schs\Current control\NCC_GND_troubleshot.sch (Sheet: 1/1)
